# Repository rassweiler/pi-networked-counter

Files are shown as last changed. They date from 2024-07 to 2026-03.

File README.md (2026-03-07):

# pi-networked-counter
Network attached counter using Pi5, python, pyqt6, and sqlite

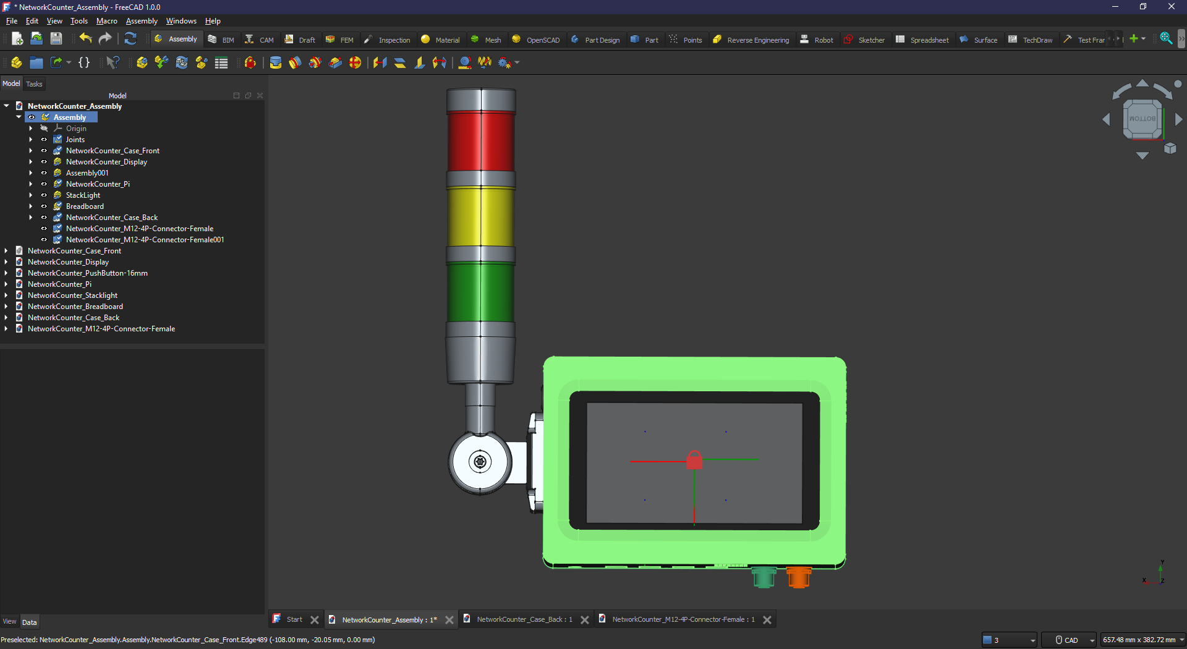
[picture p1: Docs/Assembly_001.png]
Assembly

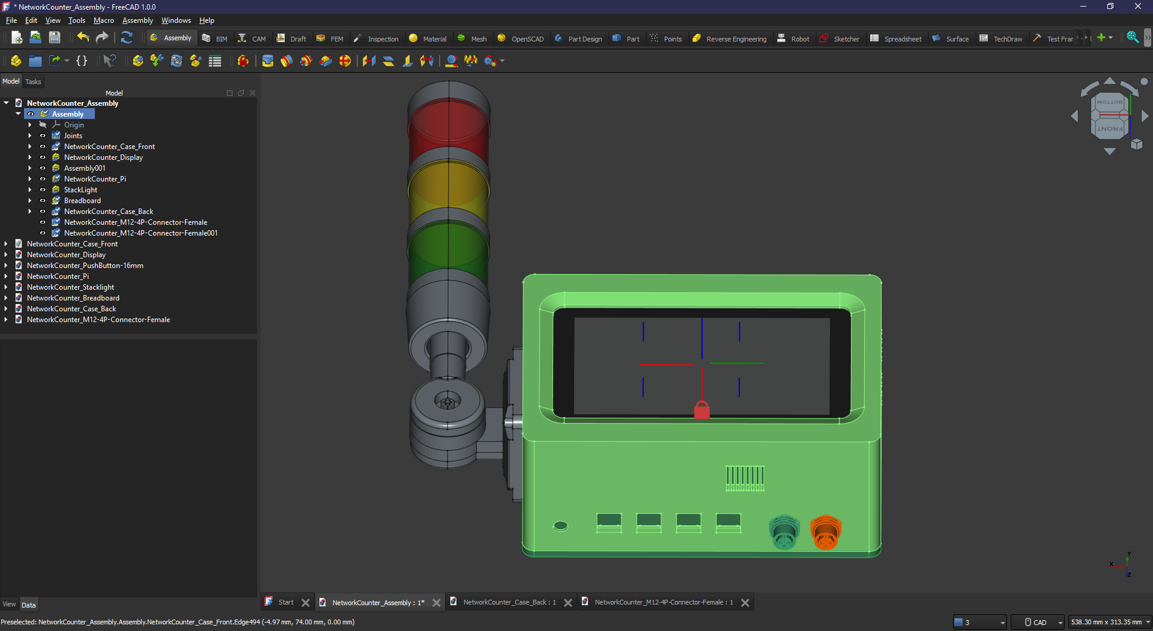
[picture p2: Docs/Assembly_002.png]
Assembly IO

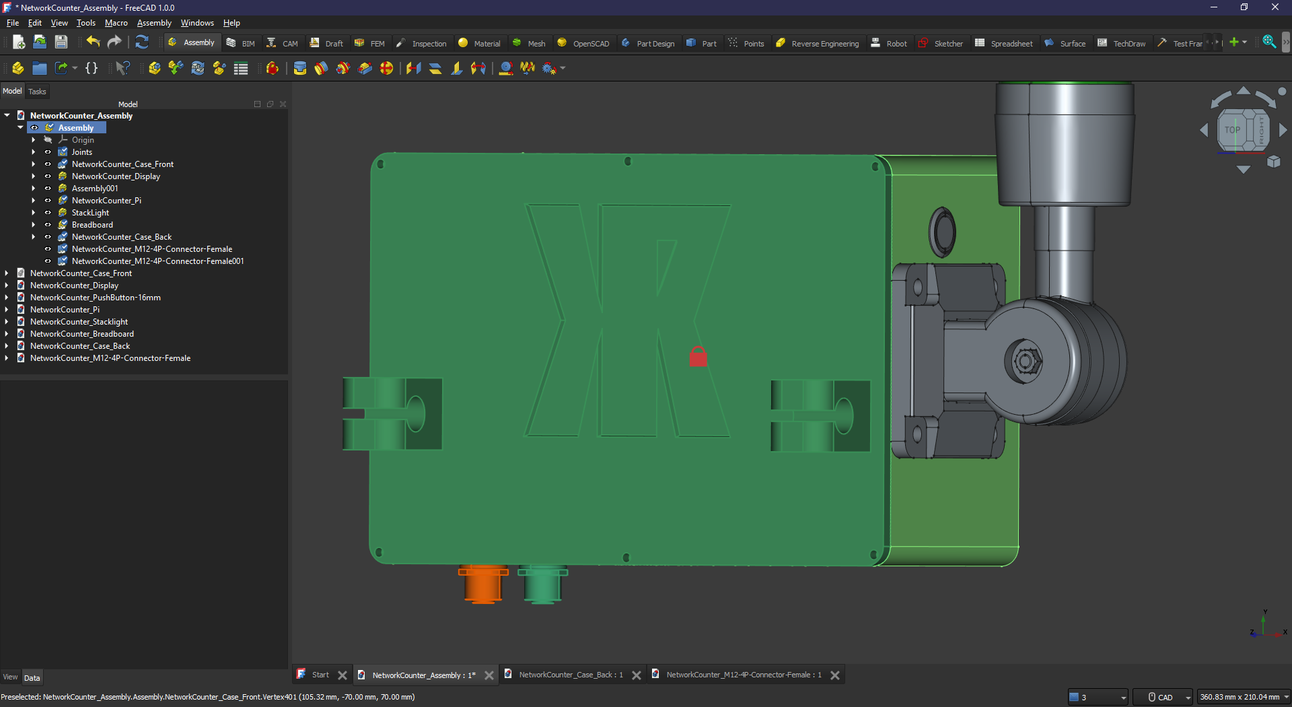
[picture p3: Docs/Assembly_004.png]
Assembly Rear

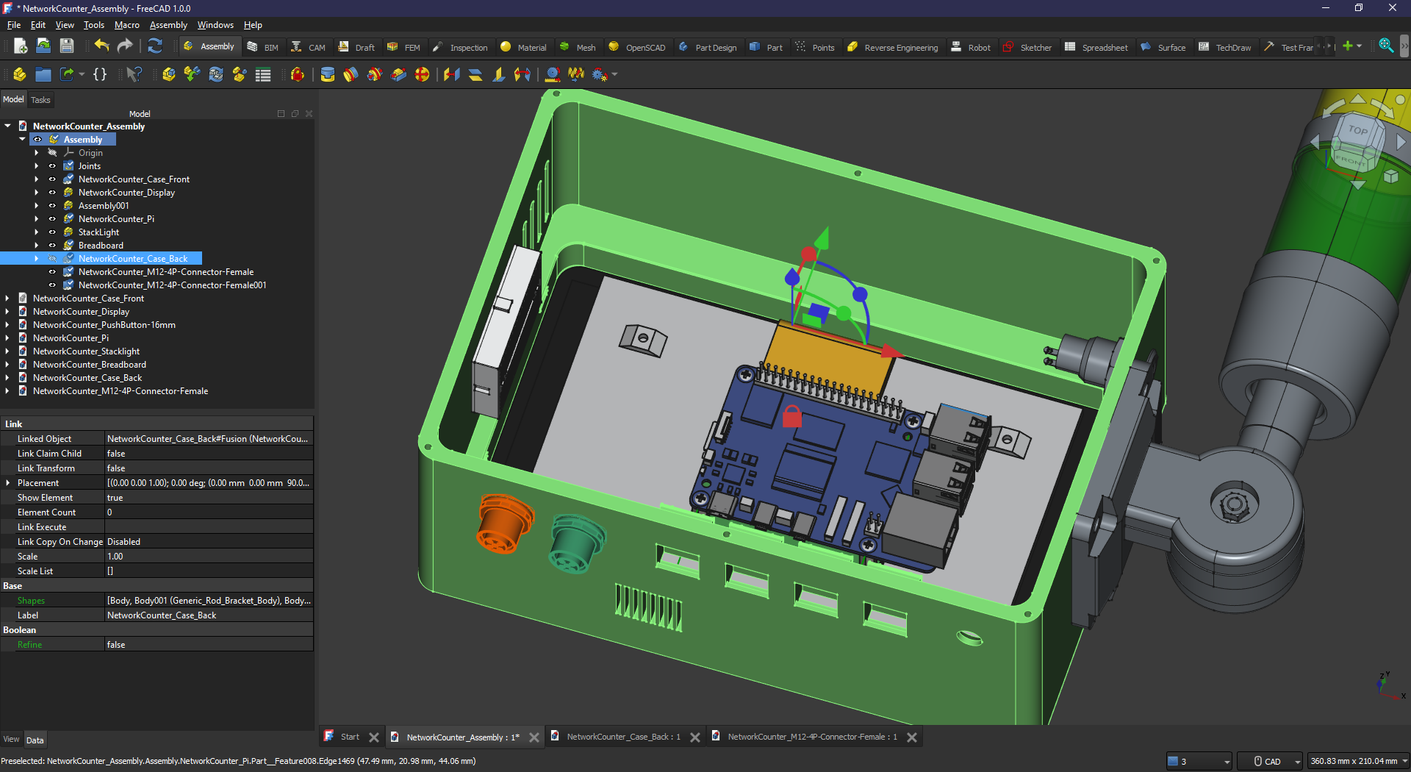
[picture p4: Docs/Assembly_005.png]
Assembly Opened

Sensor Assembly
Sensor Assembly 2
Sensor Assembly Opened

## Dev Setup (Linux)

- clone repository:
```
git clone https://github.com/rassweiler/pi-networked-counter.git && cd pi-networked-counter
```

- Setup python environment:
```
python3 -m venv venv

source venv/bin/activate

pip3 install gpiozero lgpio msal msal_extensions python-dotenv pygobject
```

- Install optional packages:
```
sudo apt install qtcreator sqlitebrowser
```

## Device Setup (Pi5+)

### Base Version Part List
- 1 [Raspberry Pi 5+](https://www.canakit.com/raspberry-pi-5-8gb.html?cid=CAD&src=raspberrypi)
- 1 [Raspberry Pi 5+ Power Supply](https://www.canakit.com/official-raspberry-pi-5-power-supply-27w-usb-c.html?defpid=4863)
- 1 [Micro SSD](https://www.amazon.ca/Samsung-Memory-Adapter-Limited-Warranty/dp/B09FFD6R2B/)
- 1 [Raspberry Pi 7" screen](https://www.canakit.com/raspberry-pi-lcd-display-touchscreen.html)
- 1 [Pi5 Diplay adapter cable](https://www.canakit.com/raspberry-pi-5-display-cable.html)
- 2 [Harting Cables](https://www.digikey.ca/en/products/detail/harting/21350102507010/16669171)
- 2 [M12 AMP Connector Male](https://www.digikey.ca/en/products/detail/te-connectivity-amp-connectors/T4171010005-001/7927449)
- 2 [M12 AMP Connector Female](https://www.digikey.ca/en/products/detail/te-connectivity-amp-connectors/T4171110005-001/7221411)
- 1 [Pack of jumper pin connectors](https://www.amazon.ca/Elegoo-120pcs-Multicolored-Breadboard-arduino/dp/B01EV70C78/)
- 1 [Roll of PETG filament](https://www.prusa3d.com/product/prusament-petg-anthracite-grey-1kg/)
- 2 [IR Emitter/ Receiver 5mm 3.3v](https://www.adafruit.com/product/2168#technical-details)
- 1 [Ethernet Keystone Inline](https://www.amazon.ca/5PACK-CAT6-Keystone-Inline-Coupler-White/dp/B0116T7XMQ/)
- 1 [Ethernet Patch Cable](https://www.amazon.ca/Cat-Ethernet-Cable-0-5ft-Pack/dp/B0CMQG7GS1)
- 1 [USB C Keystone Jack Adapter USB 3.1](https://www.amazon.ca/AAOTOKK-Keystone-Adapter-Type-C-Coupler/dp/B07Z947FRN)
- 1 [USB C patch cable](https://www.amazon.ca/Silkland-Charging-Compatible-MacBook-Samsung/dp/B0CQ4SX256)
- 1 [USB A Keystone Jack Cable](https://www.amazon.ca/Keystone-Haokiang-Adapters-Connector-Cable-20CM/dp/B07JFRLLQF)
- 1 [22awg Wire 2 Conductor 25ft](https://www.digikey.ca/en/products/detail/prysmian/C6348A-46-10/2761061)
- 1 [Rugged Metal Pushbutton - 16mm White Momentary](https://www.adafruit.com/product/558)
- 2 [Wire Connector Pack](https://www.amazon.ca/Connector-Solderless-Connectors-Stripping-Electrical/dp/B08929GXGK)
- 1 [GPIO Ribbon Cable](https://www.adafruit.com/product/1988)
- 1 [GPIO Header](https://www.pishop.ca/product/40-pin-gpio-connector-header/)

### Stacklight Version Part List
- 1 [DC Power Panel Jack](https://www.amazon.ca/DIYhz-Socket-Female-Mounting-Connector/dp/B079D6P26P)
- 1 [DC Power Supply](https://www.amazon.ca/ALITOVE-Adapter-Converter-100-240V-5-5x2-1mm/dp/B01GEA8PQA)
- 1 [Through-Hole Resistors - 1K ohm 5% 1/4W](https://www.adafruit.com/product/4294)
- 1 [Through-Hole Resistors - 220 ohm 5% 1/4W](https://www.adafruit.com/product/2780)
- 1 [AQY210EH SSR](https://www.digikey.ca/en/products/detail/panasonic-electric-works/AQY210EH/513082)
- 1 [Tower Light - Red Yellow Green Alert Light](https://www.adafruit.com/product/2993#technical-details)
- 1 [Tiny Premium Breadboard](https://www.adafruit.com/product/65#description)

### Optional Parts
- 1 [Pi5 POE Hat](https://www.pishop.ca/product/power-over-ethernet-hat-f-for-raspberry-pi-5-cooling-fan-802-3af-at/)

### Pi Software

- Update system
```
sudo apt update && sudo apt upgrade
```

- Install packages
```
sudo apt install < .packages
```

- Disable sudo NOPASSWD:
```
sudo nano /etc/sudoers.d/010_pi-nopasswd

remove NOPASSWD:
```

- Enable sudo logging:
```
sudo visudo

Insert:

Defaults    logfile=/var/log/sudo
```

- Harden ssh config:
```
sudo nano /etc/ssh/sshd_config

PermitRootLogin prohibit-password
MaxAuthTries 5
MaxSessions 3
MaxStartups 3:90:15
PasswordAuthentication no
```

- Harden ssh keys:
```
echo -e "# Restrict key exchange, cipher, and MAC algorithms, as per sshaudit.com\n# hardening guide.\n KexAlgorithms sntrup761x25519-sha512,sntrup761x25519-sha512@openssh.com,curve25519-sha256,curve25519-sha256@libssh.org,gss-curve25519-sha256-,diffie-hellman-group16-sha512,gss-group16-sha512-,diffie-hellman-group18-sha512,diffie-hellman-group-exchange-sha256\n\nCiphers chacha20-poly1305@openssh.com,aes256-gcm@openssh.com,aes256-ctr,aes192-ctr,aes128-gcm@openssh.com,aes128-ctr\n\nMACs hmac-sha2-256-etm@openssh.com,hmac-sha2-512-etm@openssh.com,umac-128-etm@openssh.com\n\nHostKeyAlgorithms sk-ssh-ed25519-cert-v01@openssh.com,ssh-ed25519-cert-v01@openssh.com,rsa-sha2-512-cert-v01@openssh.com,rsa-sha2-256-cert-v01@openssh.com,sk-ssh-ed25519@openssh.com,ssh-ed25519,rsa-sha2-512,rsa-sha2-256\n\nRequiredRSASize 3072\n\nCASignatureAlgorithms sk-ssh-ed25519@openssh.com,ssh-ed25519,rsa-sha2-512,rsa-sha2-256\n\nGSSAPIKexAlgorithms gss-curve25519-sha256-,gss-group16-sha512-\n\nHostbasedAcceptedAlgorithms sk-ssh-ed25519-cert-v01@openssh.com,ssh-ed25519-cert-v01@openssh.com,sk-ssh-ed25519@openssh.com,ssh-ed25519,rsa-sha2-512-cert-v01@openssh.com,rsa-sha2-512,rsa-sha2-256-cert-v01@openssh.com,rsa-sha2-256\n\nPubkeyAcceptedAlgorithms sk-ssh-ed25519-cert-v01@openssh.com,ssh-ed25519-cert-v01@openssh.com,sk-ssh-ed25519@openssh.com,ssh-ed25519,rsa-sha2-512-cert-v01@openssh.com,rsa-sha2-512,rsa-sha2-256-cert-v01@openssh.com,rsa-sha2-256\n\n" > /etc/ssh/sshd_config.d/ssh-audit_hardening.conf
```

- Remove avahi:
```
sudo systemctl stop avahi-daemon && sudo systemctl disable avahi-daemon

sudo apt purge avahi-daemon -y
```

- Remove CUPS:
```
sudo systemctl stop cups && sudo systemctl disable cups

sudo apt purge cups -y 
```

- PI configure
Set the locale to UTF-8

- Setup keyring for sharepoint integration
Run seahorse and make sure there is a default keystore

- clone repository to PI:
```
git clone https://github.com/rassweiler/pi-networked-counter.git && cd pi-networked-counter
```

- Copy the desktop file to autostart the app:
```
sudo cp objectcounter.desktop /etc/xdg/autostart/objectcounter.desktop
```

- Add panel icon
```
cp objectcounter.desktop ~/.local/share/applications/
```

Then restart the system to get the app in the menu under other, then right click the app and select add to taskbar

- Setup startup IO for push button
```
echo "dtoverlay=gpio-poweroff,gpiopin=25,active_low" >> /boot/firmware/config.txt
```

### Sharepoint Setup (Optional)

- Add to the `.settup.toml` file your sharepoint access details:
```
[sharepoint]
authority = "https://login.microsoftonline.com/{AID}"
client = "{CID}"
scopes = 'User.ReadBasic.All Files.ReadWrite Sites.ReadWrite.All'
endpoint = "https://graph.microsoft.com/v1.0/me" 
```

- run the `get_token.sh` script once to initialise your sharepoint token, it should provide a link and a key to login using a browser.

### Print Parts

- Print out the [Front case](./Models/Exports/NetworkCounter_Case_Front_Print.3mf) section (Should contain the screen brackets as well)
- Print out the [Rear case](./Models/Exports/NetworkCounter_Case_Back_Print.3mf) section
- Print out the [Sensor case](./Models/Exports/NetworkCounter_SensorCase_Front_Print.3mf) sections
- Print any required brackets/stands

### Prepare Sensors

- Connect both power wires together from the IR emitter and receiver
- Connect both ground wires together from the IR emitter and receiver
- Solder the M12 AMP Connector Male to the sensors following the pinout below

### Sensor Pinout To Cable

- Pin 1 (Brown): 3.3V 
- Pin 2 (White): Unused 
- Pin 3 (Blue): Emitter signal (Yellow) 
- Pin 4 (Black): Ground 
- Pin 5 (Gray): Unused
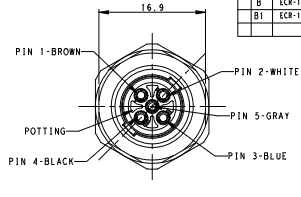
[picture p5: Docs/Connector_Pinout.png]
Connector Pinout


### Lightstack Pinout

- Cable Brown: 12V 
- Cable Green: Green LED 
- Cable Yellow: Yellow LED 
- Cable Red: Red LED 

### Pi5 Wiring 

- Pin 1 (3.3V): To infeed sensor pin 1
- Pin 2 (5V): To Display pin 5 (5V)
- Pin 6 (GND): To Display pin 1 (GND)
- Pin 9 (GND): To infeed sensor pin 4
- Pin 11: To infeed sensor pin 3
- Pin 13: To stack light green wire
- Pin 14 (GND): To outfeed sensor pin 4
- Pin 15: To stack light yellow wire
- Pin 16: To outfeed sensor pin 3
- Pin 17: (3.3V): To outfeed sensor pin 1
- Pin 18: To stack light red wire
- Pin 22: To power led +
- Pin 25 (GND): To dev board for ground
- Pin 30 (GND): To power led -

### Assembly Schematic
The Pi5 board is not entirely accurate, the J2 and J8 pins are proper however.
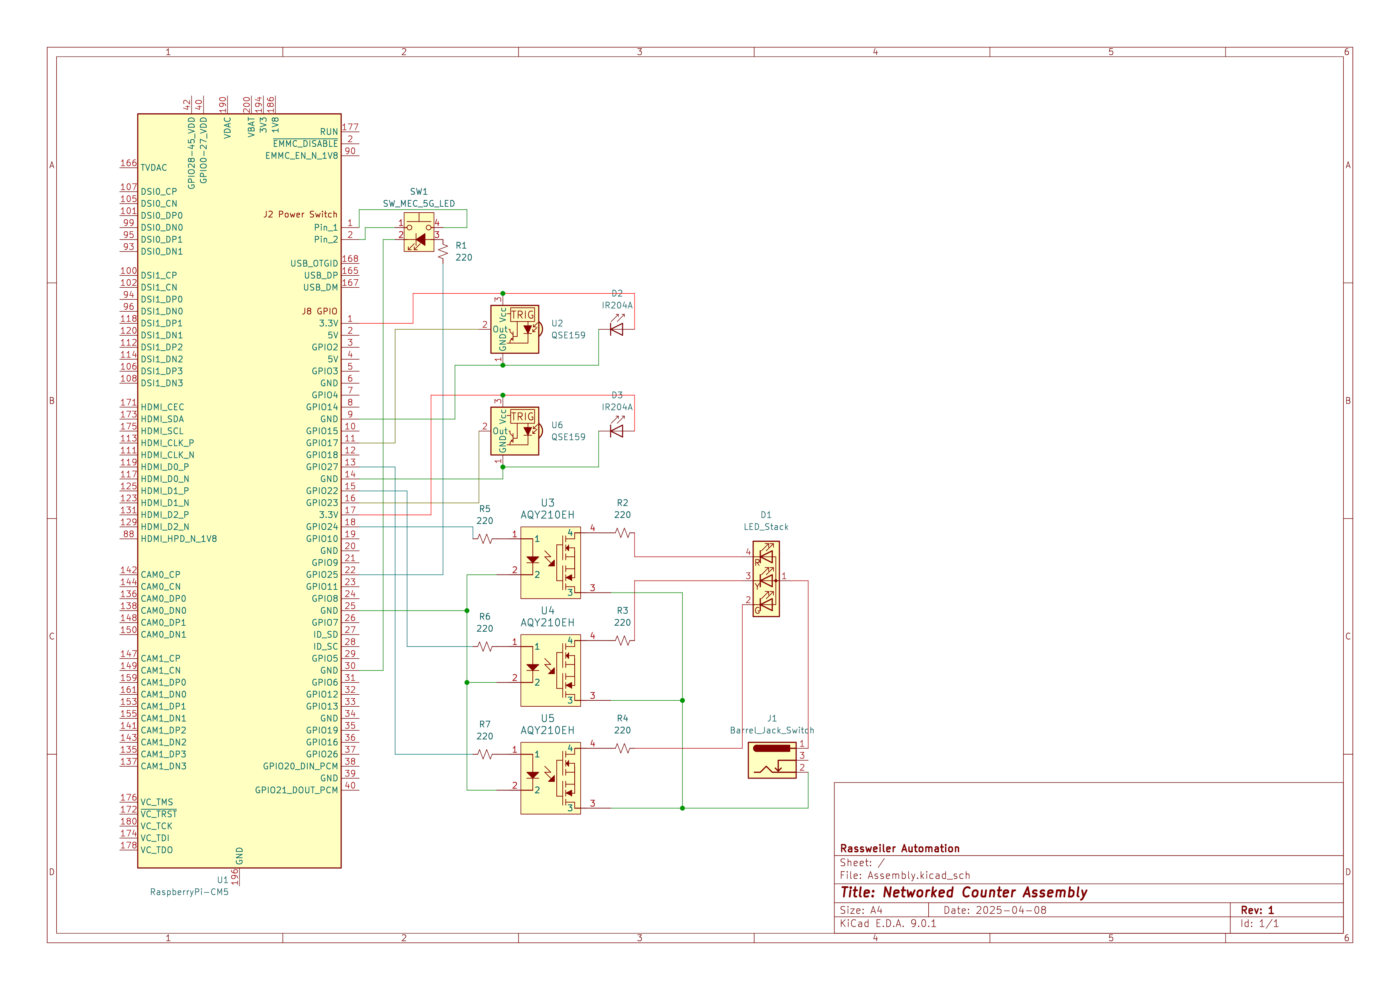
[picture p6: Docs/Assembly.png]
Schematic


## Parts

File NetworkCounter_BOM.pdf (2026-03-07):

Name | Part # | Unit Price

### Units Per Counter

Total Cost | Link | Purchased | Tracking Number
Harting Cable | 21348485484050 | $27.26
2 | $54.52 | https://www.digikey.ca/en/products/detail/harting/21348485484050/7917624
| | Y | Delivered
M12 AMP Connector Male | T4171010005-001 | $15.14
2 | $30.28 | https://www.digikey.ca/en/products/detail/te-connectivity-amp-connectors/T4171010005-001/7927449
| | Y | Delivered
M12 AMP Connector Female | T4171310004-001 | $14.20
2 | $28.40 | https://www.digikey.ca/en/products/detail/te-connectivity-amp-connectors/T4171310004-001/7221375
| | Y | Delivered
Tall Headers 4 & 40 | $11.95
1 | $11.95 | https://www.pishop.ca/product/4-40-pin-extra-tall-header-push-fit-version-poe-hat-set/
| | Y | Delivered
Pi5 POE Hat | $33.95
1 | $33.95 | https://www.pishop.ca/product/power-over-ethernet-hat-f-for-raspberry-pi-5-cooling-fan-802-3af-at/
| | Y | Delivered
Raspberry Pi 5 8GB | $111.95
1 | $111.95 | https://www.canakit.com/raspberry-pi-5-8gb.html?cid=CAD&src=raspberrypi
| | Y | Delivered
Jumper Pin Connectors | $12.99
1 | $12.99 | https://www.amazon.ca/Elegoo-120pcs-Multicolored-Breadboard-arduino/dp/B01EV70C78/
| | Y | Delivered
Breadboard | 340-002-1 | $75.54
1 | $75.54 | https://www.digikey.ca/en/products/detail/digilent-inc/340-002-1/9556131
| | Y | Delivered
Raspberry Pi 7" Touchscreen | RSP-DISPLAY | $85.95
1 | $85.95 | https://www.canakit.com/raspberry-pi-lcd-display-touchscreen.html
| | Y | Delivered
Raspberry Pi 5 Display Cable | CBL-DISP-MINI-200 | $1.40
1 | $1.40 | https://www.canakit.com/raspberry-pi-5-display-cable.html
| | Y | Delivered
Raspberry Pi 5 Power Supply | $16.95
1 | $16.95 | https://www.canakit.com/official-raspberry-pi-5-power-supply-27w-usb-c.html?defpid=4863
| | Y | Delivered
Fillamentum Ghost White PETG Filament - 1.75mm | M-US3-YXAA | $56.00
1 | $56.00 | https://www.matterhackers.com/store/l/fillamentum-petg-filament/sk/MUS3YXAA
| | Y | Delivered
Micro HDMI to HDMI Adapter | $12.99
1 | $12.99 | https://www.amazon.ca/Cable-Matters-Plated-Female-Adapter/dp/B00JDRHQ58/
| | Y | Delivered
Samsung 256GB EVO Plus Micro SD | MB-MC256K | $32.49
1 | $32.49 | https://www.amazon.ca/Samsung-Memory-Adapter-Limited-Warranty/dp/B09FFD6R2B/
| | Y | Delivered
Memory Card Reader | $13.99
1 | $13.99 | https://www.amazon.ca/Memory-Reader-BENFEI-USB-C-Adapter/dp/B08P517NW5/
| | Y | Delivered
Ultrasonic Distance Sensor - 3.3V | US-100 | $5.95
2 | $11.90 | https://www.pishop.ca/product/us-100-ultrasonic-sensor-with-temperature-compensation-range/
| | Y | Delivered
Ethernet Wall Plate 1 Port Cat6 RJ45 Keystone | $9.99
1 | $9.99 | https://www.amazon.ca/VCE-Ethernet-Keystone-Coupler-Network/dp/B0C3J1FZZN/
| | Y | Delivered
Cat6 1' Patch Cables | $13.99
1 | $13.99 | https://www.amazon.ca/Cable-Matters-5-Pack-Snagless-Ethernet/dp/B00C4U030G
| | Y | Delivered
USB C Keystone Jack Cable | $10.19
1 | $10.19 | https://www.amazon.ca/Poyiccot-Keystone-Cable-White-Black/dp/B08BJJZV2Z
USB A Keystone Jack Cable | $11.51
1 | $11.51 | https://www.amazon.ca/Keystone-Haokiang-Adapters-Connector-Cable-20CM/dp/B07JFRLLQF

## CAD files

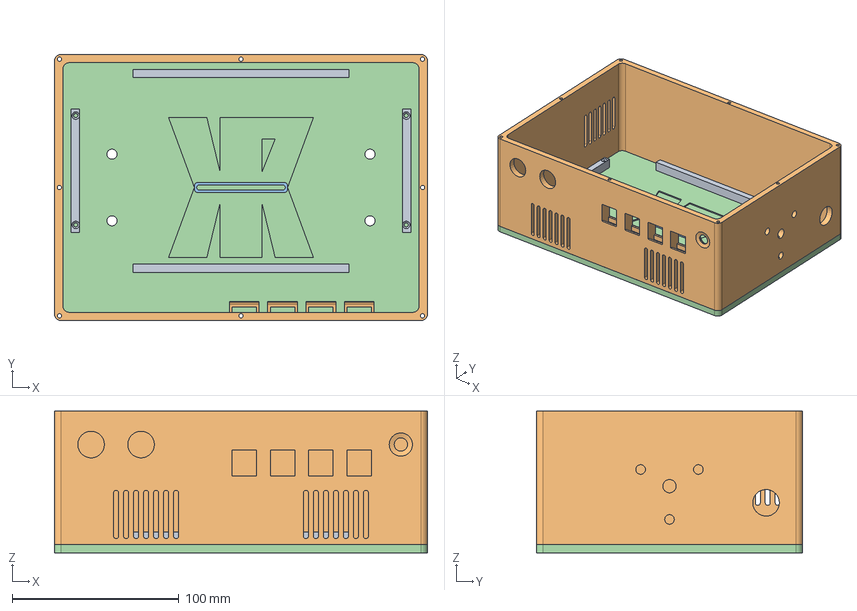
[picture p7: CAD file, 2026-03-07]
Models/NetworkCounter_Case.FCStd
224.0 x 160.0 x 85.0 mm
NetworkCounter_Case_Face
NetworkCounter_Case_Walls
NetworkCounter_Case_Bracket
NetworkCounter_Case_Cover

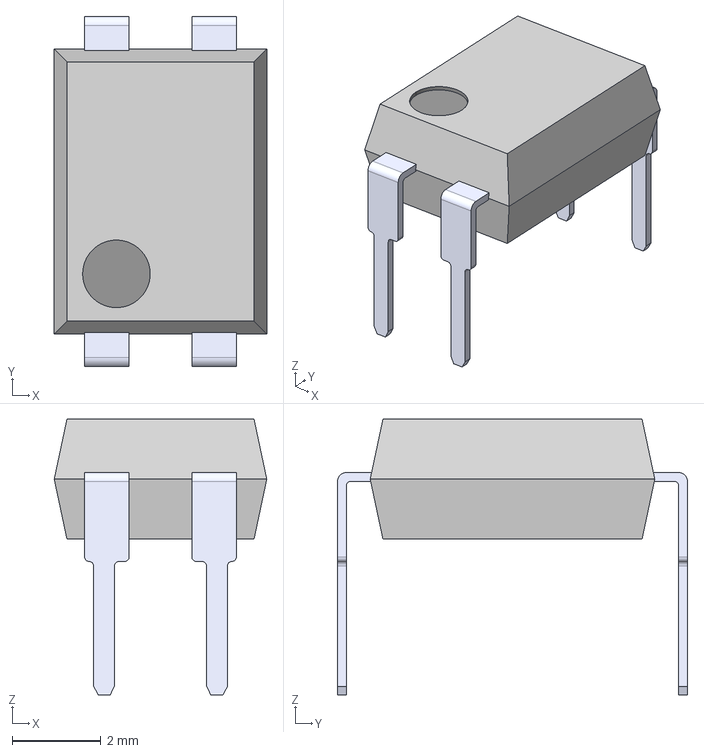
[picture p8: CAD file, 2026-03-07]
Schematics/LED_Board/panasonic_AQY210EH.step
4.78 x 7.87 x 6.20 mm

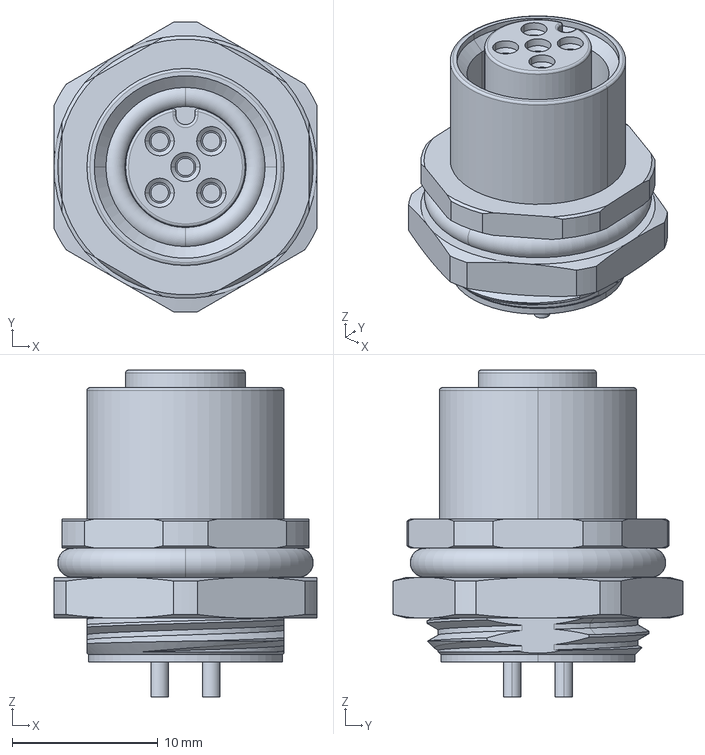
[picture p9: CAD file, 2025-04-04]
Models/NetworkCounter_M12-4P-Connector-Female.FCStd
18.0 x 19.9 x 22.4 mm

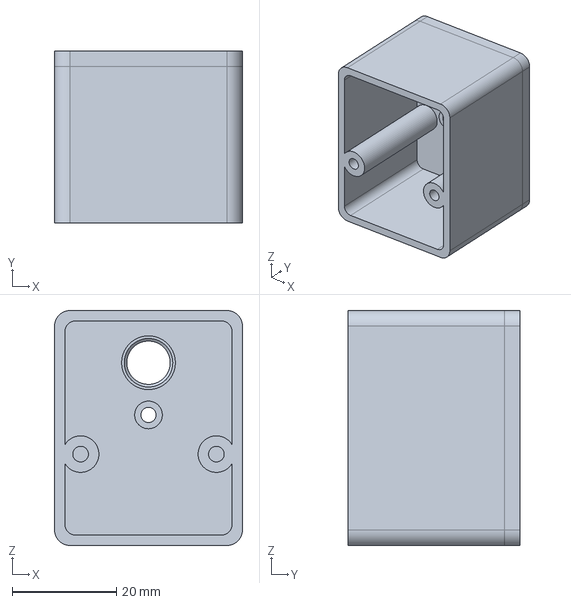
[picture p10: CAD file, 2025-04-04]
Models/NetworkCounter_SensorCase_Front_Emitter.FCStd
36.0 x 33.0 x 45.0 mm

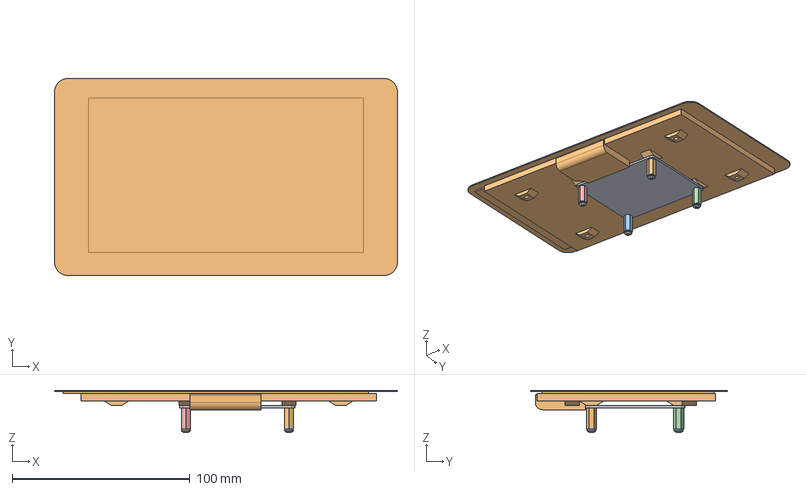
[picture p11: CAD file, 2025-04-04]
Models/NetworkCounter_Display.FCStd
193.0 x 110.8 x 23.9 mm
RPi Display Driver PCB v1
Standoff M2.5 12mm v2
Standoff M2.5 12mm v003
Standoff M2.5 12mm v004
Standoff M2.5 12mm v005
M2.5 Screw
M2.5 Screw001
M2.5 Screw002
M2.5 Screw003
RPi Touchscreen Module

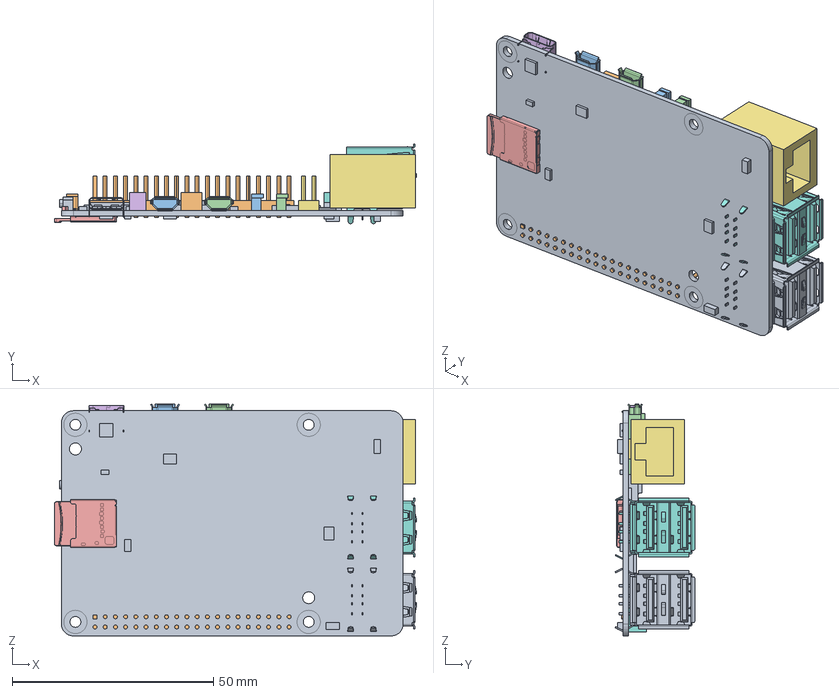
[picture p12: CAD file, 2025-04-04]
Models/NetworkCounter_Pi.FCStd
90.0 x 19.8 x 57.7 mm
PCB_for REF 060923
GPIO Header for REF
Micro HDMI for REF
Micro HDMI for REF001
SD CARD for REF
USB-C for REF
RJ45 for REF
USB for REF
USB for REF001
PCIe for REF
CAM-DISP for REF
CAM-DISP for REF001
LED for REF
BAT Header for REF
PoE Header for REF
FAN Header for REF
SWITCH for REF
UART for REF

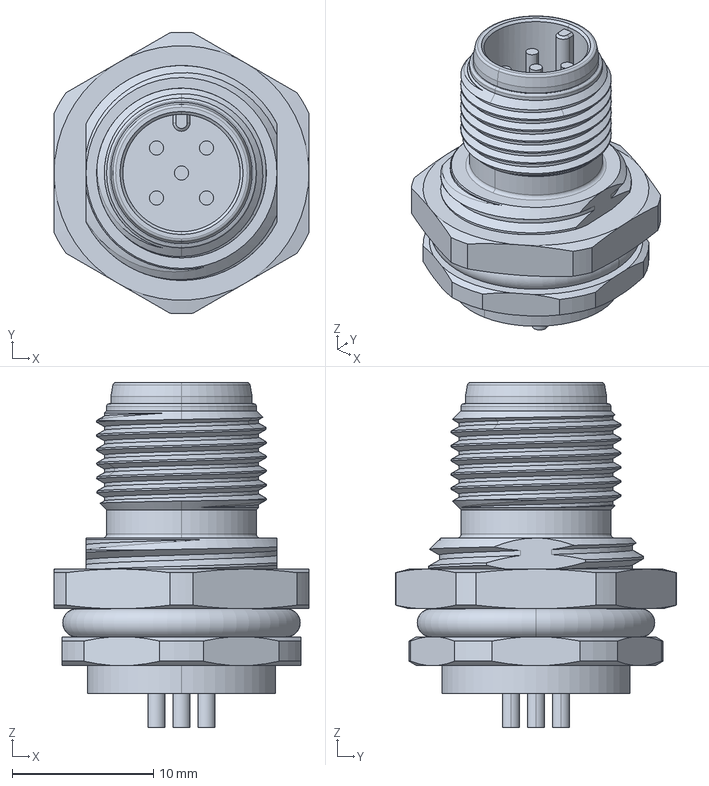
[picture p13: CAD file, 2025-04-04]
Models/NetworkCounter_M12-5P-Connector-Male.FCStd
18.0 x 19.9 x 24.4 mm

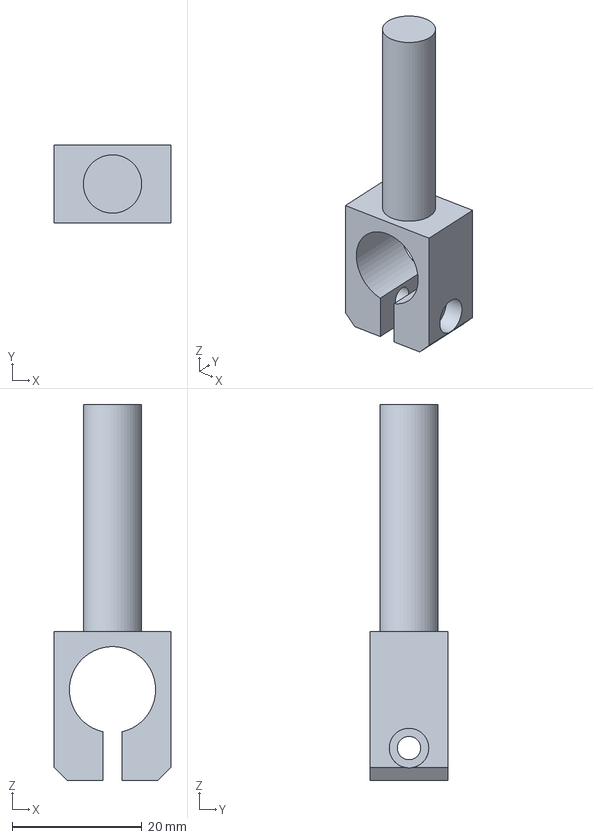
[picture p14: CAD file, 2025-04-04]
Models/NetworkCounter_Adapter_13mmHorizontal_9mmVertical.FCStd
18.0 x 12.0 x 58.0 mm

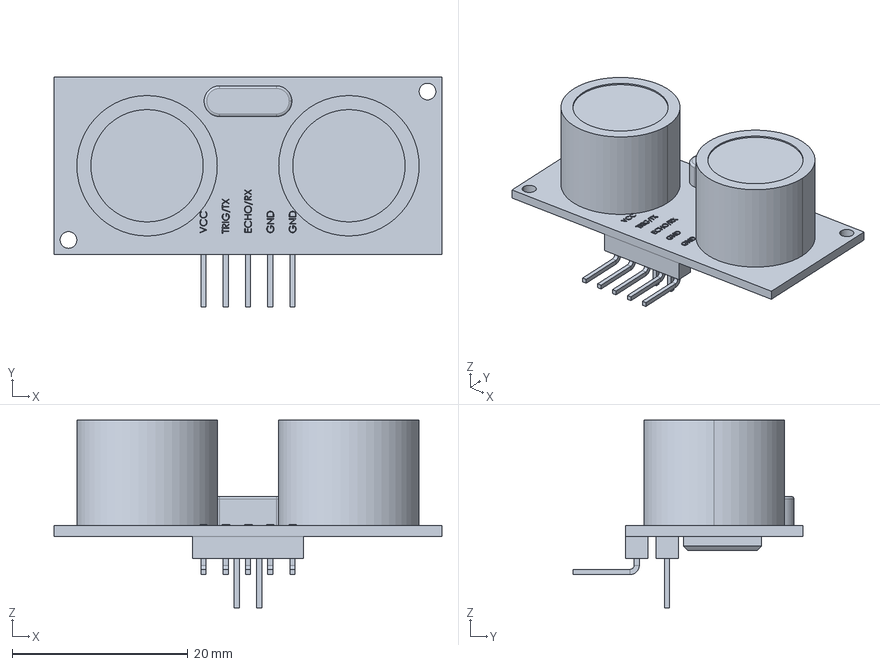
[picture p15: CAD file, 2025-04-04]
Models/NetworkCounter_US-100.FCStd
44.2 x 26.2 x 21.4 mm

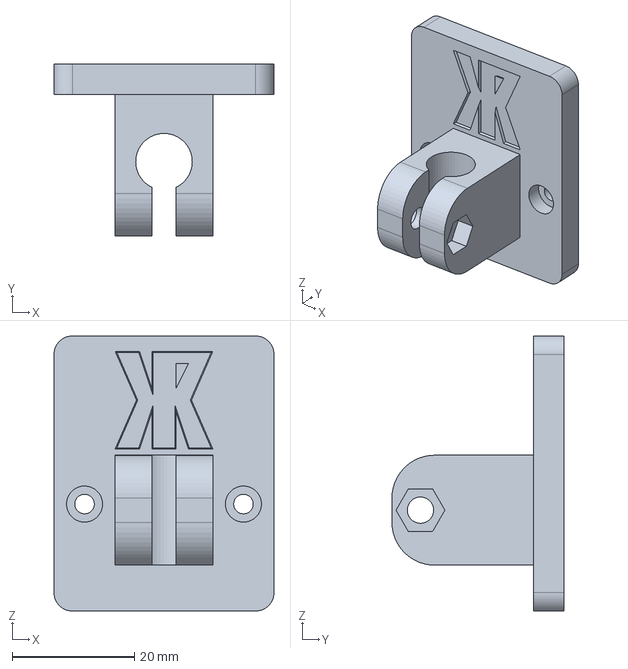
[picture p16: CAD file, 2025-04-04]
Models/NetworkCounter_SensorCase_Back.FCStd
36.0 x 28.2 x 45.0 mm

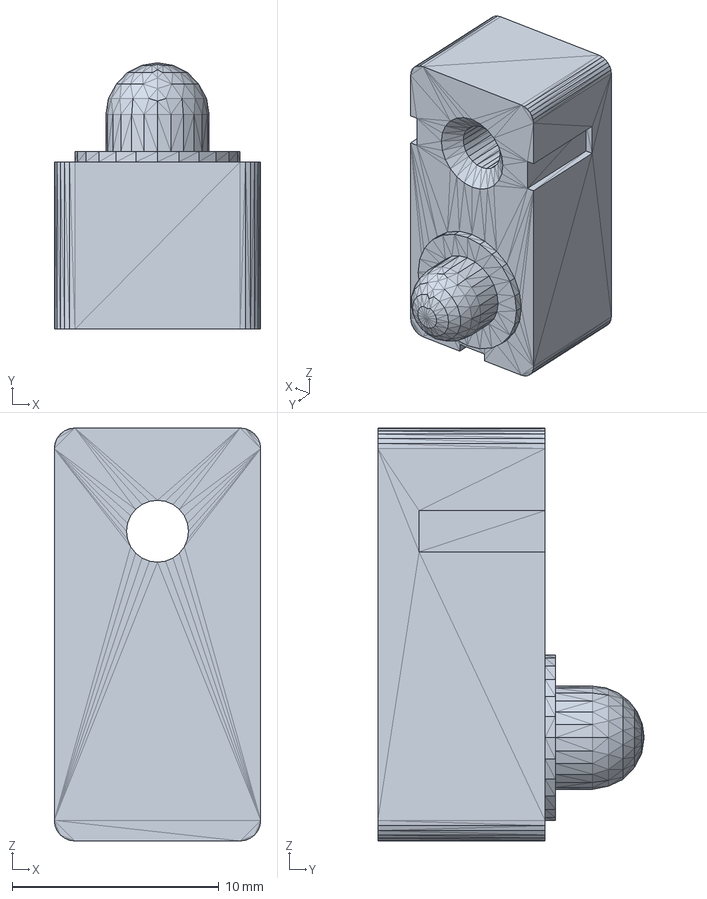
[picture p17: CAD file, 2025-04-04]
Models/NetworkCounter_IR_5mm.FCStd
10.0 x 12.9 x 20.0 mm

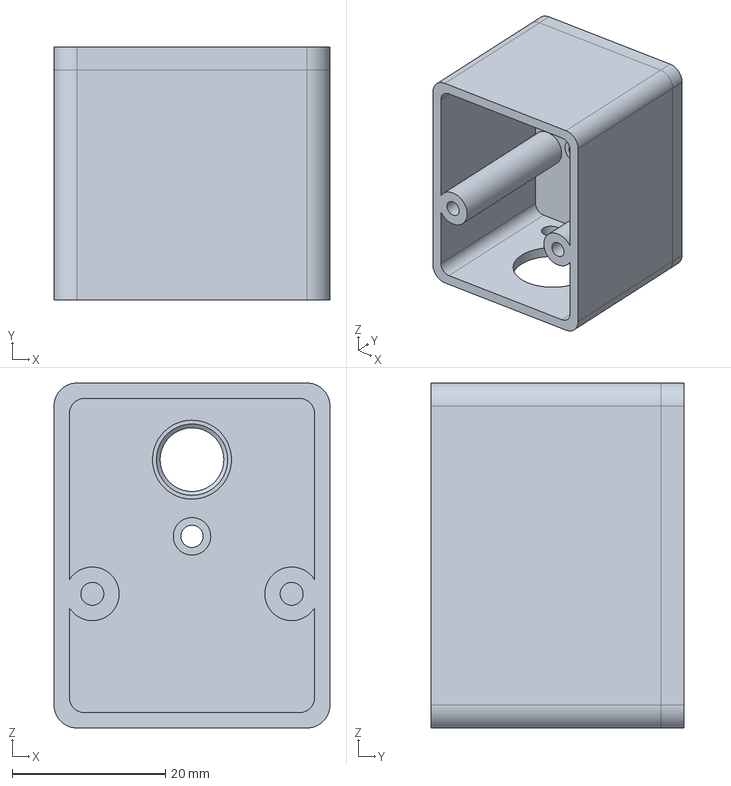
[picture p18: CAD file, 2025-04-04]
Models/NetworkCounter_SensorCase_Front_Receiver.FCStd
36.0 x 33.0 x 45.0 mm

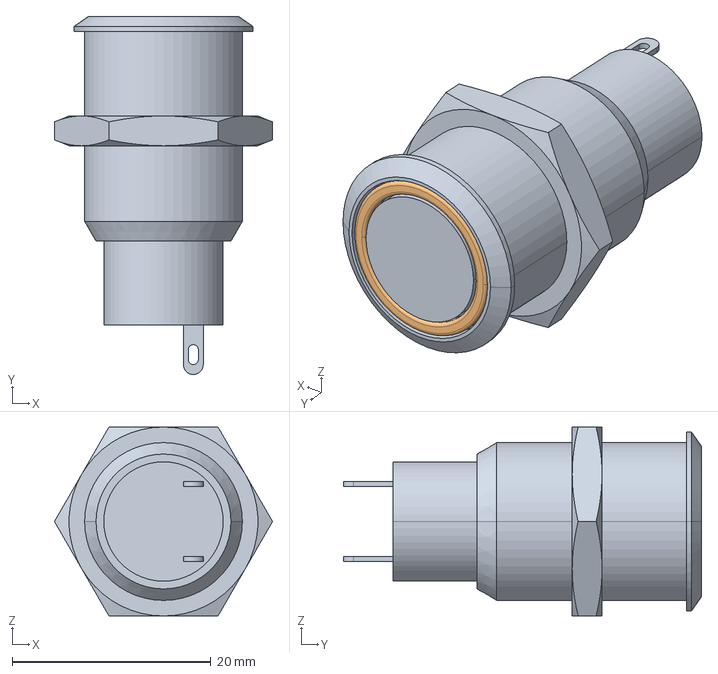
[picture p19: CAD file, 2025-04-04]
Models/NetworkCounter_PushButton-16mm.FCStd
21.9 x 36.0 x 19.0 mm
SWITCH_COM-119XX
SWITCH_COM-119XX001

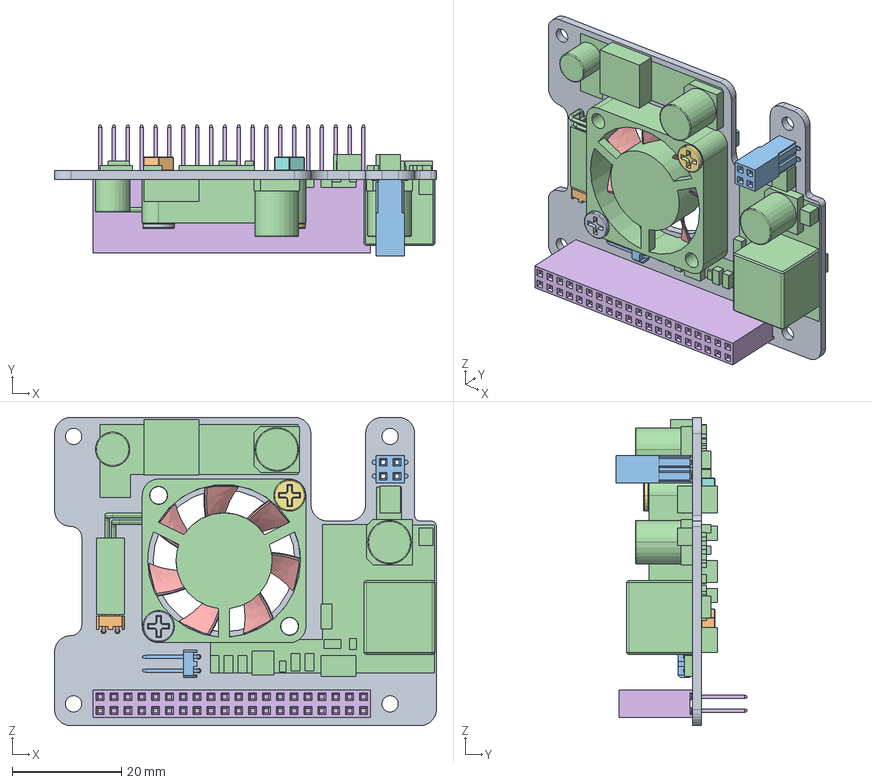
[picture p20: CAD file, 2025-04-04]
Models/NetworkCounter_POE.FCStd
70.0 x 24.1 x 56.5 mm
POE-HAT-F_PCBA
2_54_MM_DUPONT_MALE_2PIN-SMT
2_54_MM_DUPONT_MALE_2PIN-SMT001
2_54MM-H13_5-6-2X20PIN
CM2_5X12-5-SCREW
M2_5-NUT
CM2_5X12-5-SCREW001
M2_5-NUT001
HEADER-SMD-F-2_54X4P-H13_5
CORE-01

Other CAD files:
Models/NetworkCounter_Adapter_9mmHorizontal_9mmVertical.FCStd
Schematics/LED_Board/panasonic_AQY210EH.dxf

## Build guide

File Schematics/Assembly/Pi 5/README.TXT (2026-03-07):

These files have been created in version 8 of KiCAD.

Some of the 3d models need to be downloaded form the following places and put into the CM5IO.3shapes directory some models are approximations.

https://datasheets.raspberrypi.org/cm5/CM5-step.zip
https://www.molex.com/molex/products/part-detail/memory_card_socket/5033981892

The models provided in the 3dmodels directory are from various manufacturers including Diodes, Hirose, MTCONN, Toby, TRXCOM. Terms and conditions for the use of the models remain with the original manufacture.

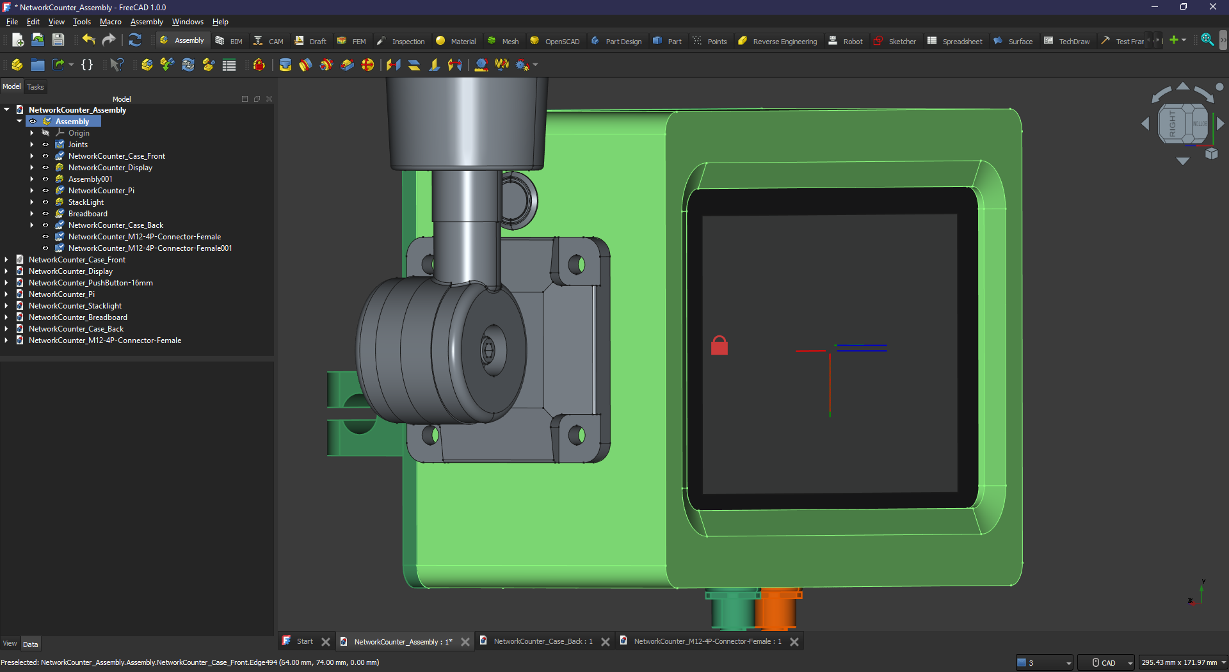
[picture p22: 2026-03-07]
Docs/Assembly_003.png

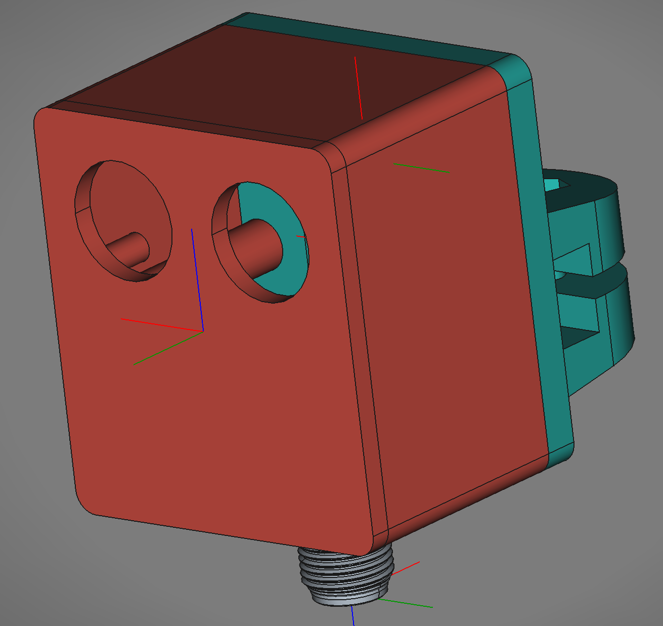
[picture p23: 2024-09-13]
Docs/SensorAssembly_01.png

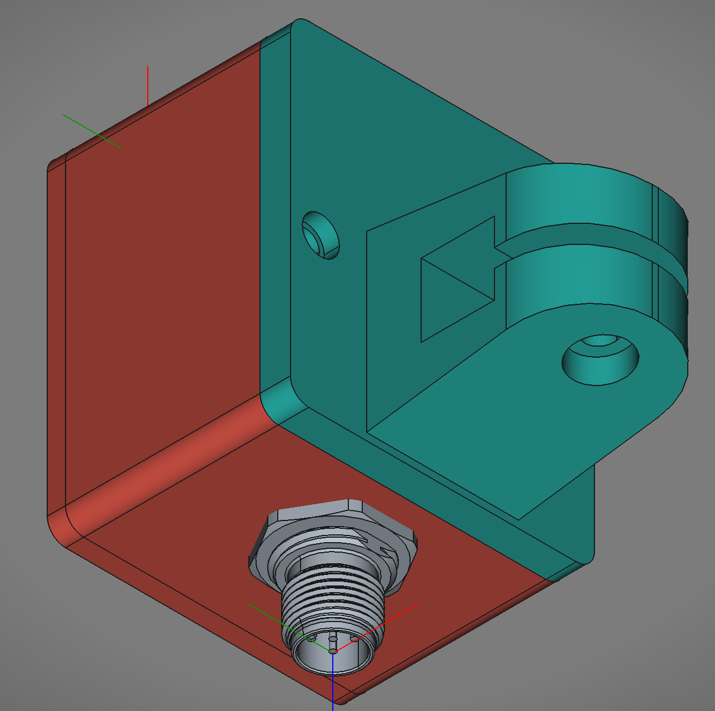
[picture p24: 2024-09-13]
Docs/SensorAssembly_02.png

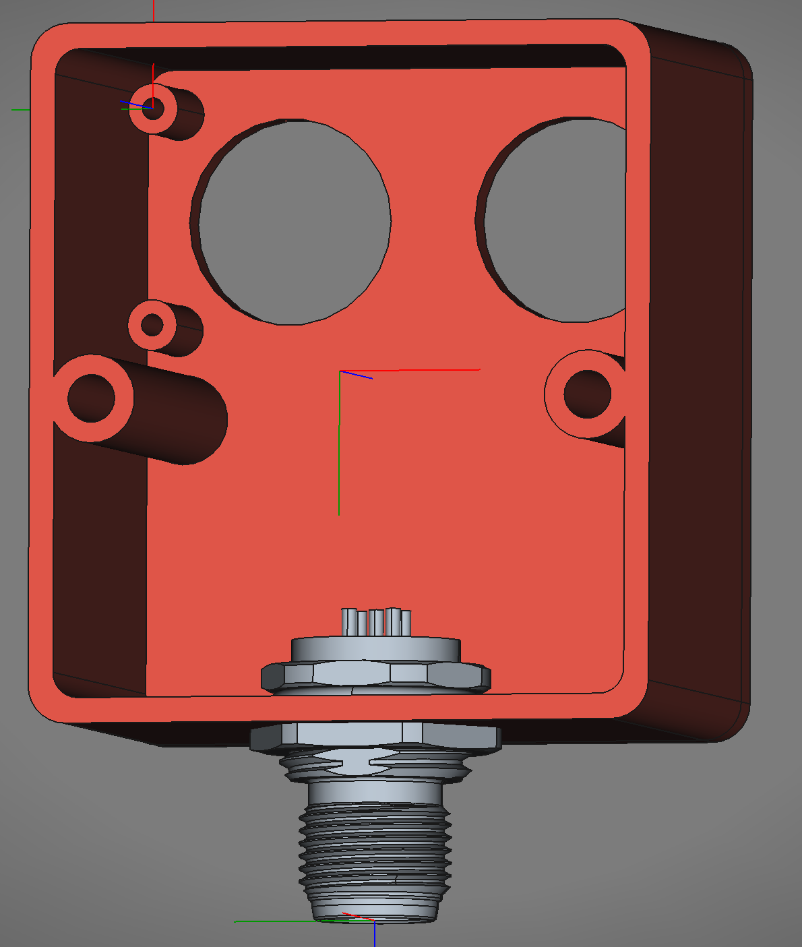
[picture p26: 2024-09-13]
Docs/SensorAssembly_03.png

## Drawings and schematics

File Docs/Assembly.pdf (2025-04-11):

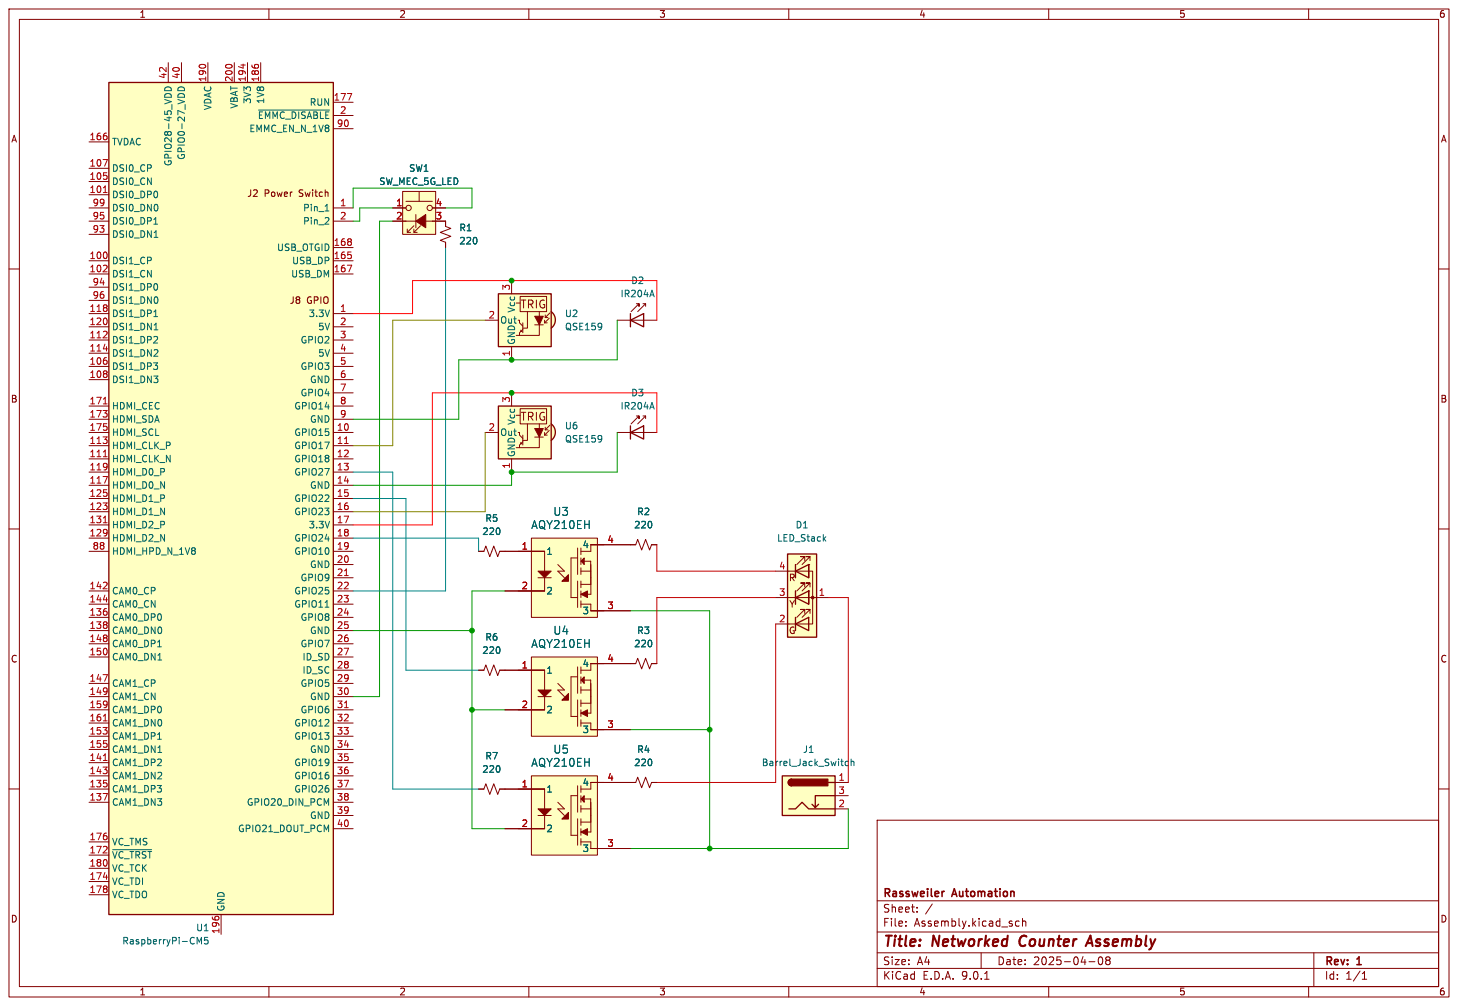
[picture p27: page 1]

File: Assembly.kicad_sch Sheet: / Rassweiler Automation

Id: 1/1 Title: Networked Counter Assembly

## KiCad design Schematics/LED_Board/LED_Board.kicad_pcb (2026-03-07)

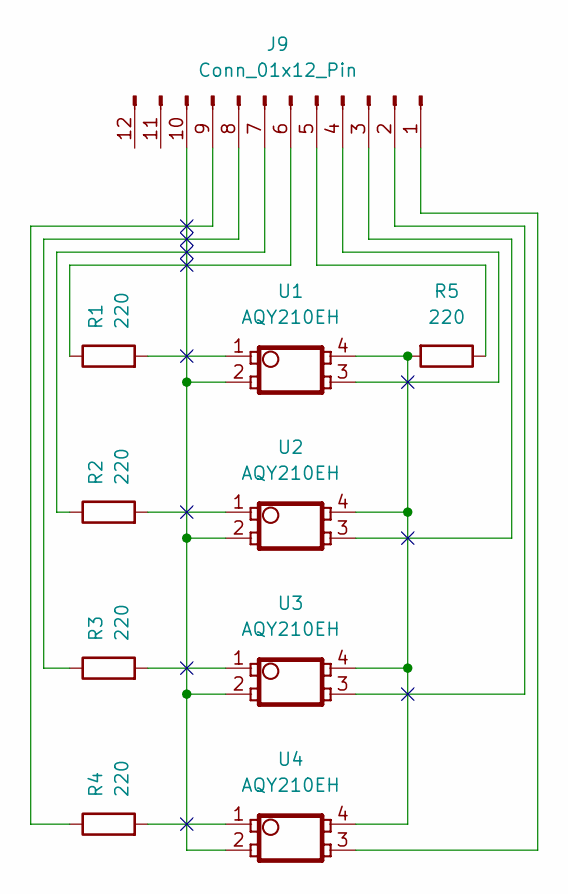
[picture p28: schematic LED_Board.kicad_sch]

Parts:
J9: Conn_01x12_Pin; PinHeader_1x12_P2.54mm_Vertical
R1, R2, R3, R4, R5: 220; R_Axial_DIN0204_L3.6mm_D1.6mm_P5.08mm_Horizontal
U1, U2, U3, U4: AQY210EH; Panasonic_AQY210EH

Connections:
unnamed: J9.1, U4.3
unnamed: J9.2, U3.3
unnamed: J9.3, U2.3
unnamed: J9.4, U1.3
unnamed: J9.5, R5.1
unnamed: J9.6, R1.1
unnamed: J9.7, R2.1
unnamed: J9.8, R3.1
unnamed: J9.9, R4.1
unnamed: J9.10, U1.2, U2.2, U3.2, U4.2
unnamed: R1.2, U1.1
unnamed: R2.2, U2.1
unnamed: R3.2, U3.1
unnamed: R4.2, U4.1
unnamed: R5.2, U1.4, U2.4, U3.4, U4.4

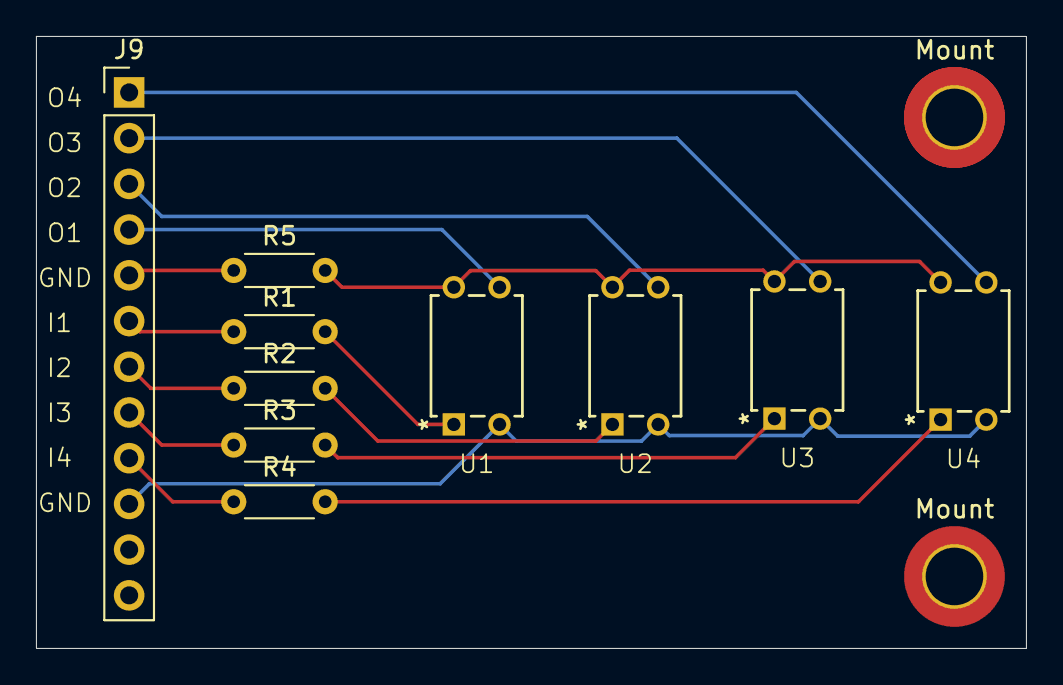
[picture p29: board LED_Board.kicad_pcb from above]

Board: 2 copper layers, 55.0 x 34.0 mm, 12 parts (0 on the bottom side), 15 nets.

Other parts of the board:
Mount: MountingHole_3.2mm_M3_DIN965_Pad_TopBottom
Mount#2: MountingHole_3.2mm_M3_DIN965_Pad_TopBottom

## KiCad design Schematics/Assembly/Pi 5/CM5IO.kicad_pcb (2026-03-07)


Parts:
C9, C18: 100n; C_0402_1005Metric; Part Description 0.1uF 10% 16V Ceramic Capacitor X7R 040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
H1, H2, H3, H4, H5, H6, H7, H8: MountingHole; MountingHole_2.7mm_M2.5_DIN965; Part Description M2.5 mounting hole; not fitted
J11: USB_C_Receptacle_USB2.0; USB_C_Receptacle_GCT_USB4105-xx-A_16P_TopMnt_Horizontal; Part Description USBC USB2 data and power connector
R9: 2.2K 1%; R_0402_1005Metric; Part Description Resistor 2.2K M1005 1% 63mW

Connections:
/+5v: C9.1, C18.1, J11.A4 (VBUS), J11.A9 (VBUS), J11.B4 (VBUS), J11.B9 (VBUS), R9.1; also elsewhere on the board
/CC1: J11.A5 (CC1); also elsewhere on the board
/CC2: J11.B5 (CC2); also elsewhere on the board
/USB2_N: J11.A7 (D-), J11.B7 (D-); also elsewhere on the board
/USB2_P: J11.A6 (D+), J11.B6 (D+); also elsewhere on the board
GND: C9.2, C18.2, J11.A1 (GND), J11.A12 (GND), J11.B1 (GND), J11.B12 (GND), J11.S1 (SHIELD), R9.2; also elsewhere on the board

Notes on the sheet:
Connectors ------- Ethernet SDCARD 40way RPI Jumpers Fan Battery
Connectors ------ M2 MKey
Discharge Resistor Needed by some Type C PSUs
TypeC Power connector
Connectors ------- HDMI 0 HDMI 1 CSI/DSI 0 CSI/DSI 1

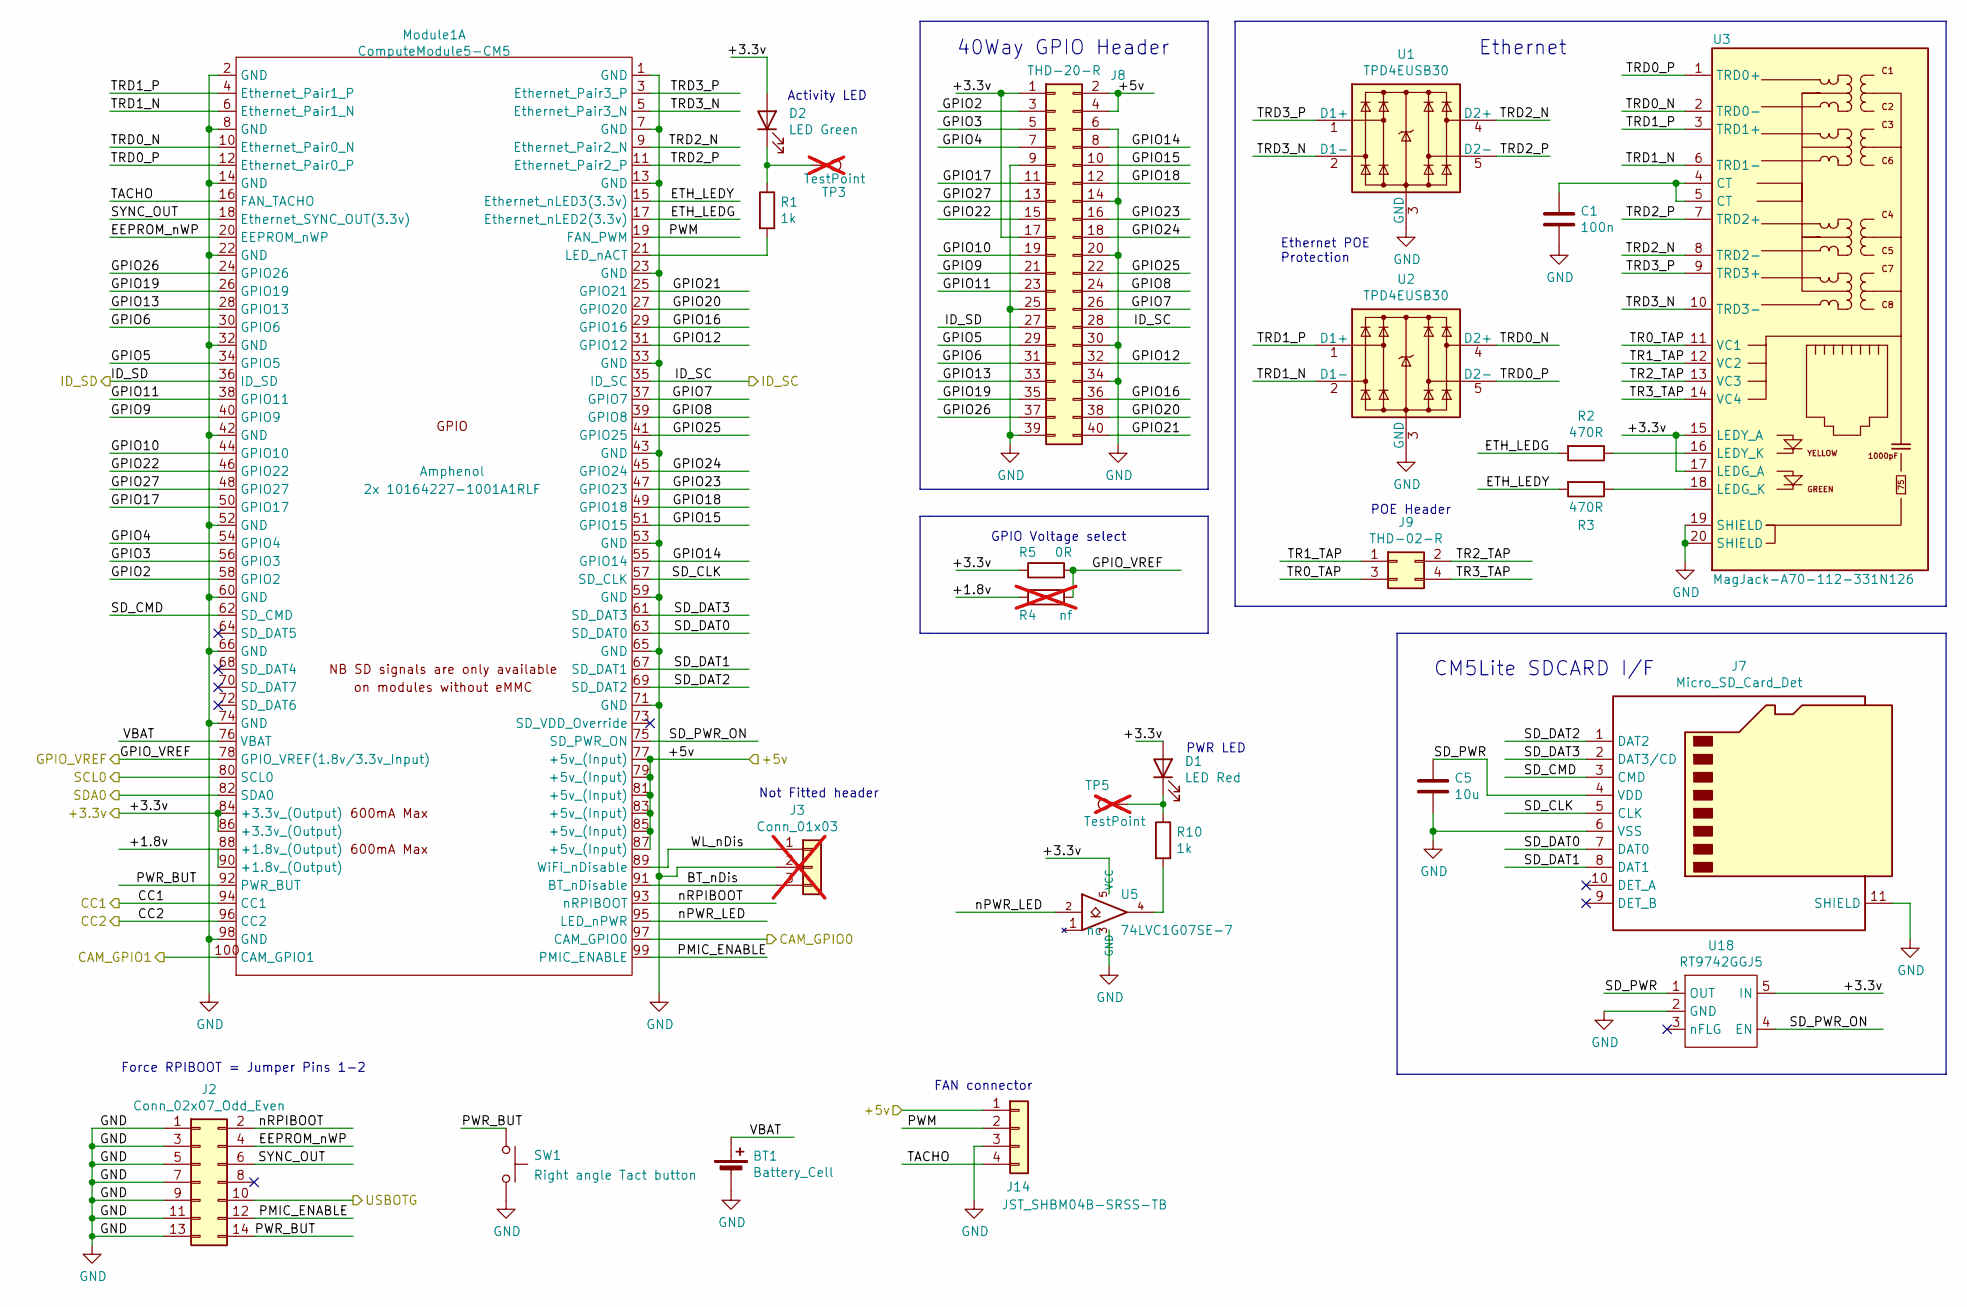
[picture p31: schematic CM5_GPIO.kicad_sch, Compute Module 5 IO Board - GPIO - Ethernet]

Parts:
BT1: Battery_Cell; BatteryHolder_Keystone_3034_1x20mm; Part Description Battery Retainer Coin, 20.0mm 1 Cell SM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
C1: 100n; C_0402_1005Metric; Part Description 0.1uF 10% 16V Ceramic Capacitor X7R 040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
C5: 10u; C_0805_2012Metric; Part Description 10uF 10% 10V Ceramic Capacitor X7R 0805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
D1: LED Red; LED_0603_1608Metric; Part Description Red 620nm LED Indication - Discrete 2.2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
D2: LED Green; LED_0603_1608Metric; Part Description Green 572nm LED Indication - Discrete 2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
J2: Conn_02x07_Odd_Even; PinHeader_2x07_P2.54mm_Vertical; Part Description PinHeader_2x07_P2.54mm_Vertical
J3: Conn_01x03; PinHeader_1x03_P2.54mm_Vertical; Part Description 3pin 0.1" connector; not fitted
J7: Micro_SD_Card_Det; SDCARD_MOLEX_503398-1892; Part Description 9 (8 + 1) Position Card Connector micro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
J8: THD-20-R; PinHeader_2x20_P2.54mm_Vertical; Part Description PinHeader_2x20_P2.54mm_Vertical
J9: THD-02-R; PinHeader_2x02_P2.54mm_Vertical; Part Description PinHeader_2x02_P2.54mm_Vertical
J14: JST_SHBM04B-SRSS-TB; JST_SH_BM04B-SRSS-TB_1x04-1MP_P1.00mm_Vertical; Part Description 4 pin vertical 1mm pitch connector
Module1: ComputeModule5-CM5; Raspberry-Pi-5-Compute-Module; Part Description 100 Position Connector Receptacle, Cent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
R1, R10: 1k; R_0402_1005Metric; Part Description Resistor 1K M1005 1% 63mW
R2, R3: 470R; R_0402_1005Metric; Part Description Resistor 470R M1005 1% 63mW
R4: nf; R_0805_2012Metric_Pad1.20x1.40mm_HandSolder; not fitted
R5: 0R; R_0805_2012Metric_Pad1.20x1.40mm_HandSolder; Part Description Resistor 0R M2012 5%
SW1: Right angle Tact button; SW_Tactile_SPST_Angled_PTS645Vx58-2LFS; Part Description Right angle through hole Tact switch
TP3, TP5: TestPoint; TestPoint_Pad_2.0x2.0mm; Part Description Test point; not fitted
U1, U2: TPD4EUSB30; USON-10_2.5x1.0mm_P0.5mm; Part Description Quad TVS diode for high speed signals (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
U3: MagJack-A70-112-331N126; TRJG0926HENL; Part Description Gigabit Ethernet Magjack
U5: 74LVC1G07SE-7; SOT-353_SC-70-5; Part Description Buffer, Non-Inverting 1 Element 1 Bit p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
U18: RT9742GGJ5; SOT-23-5; Part Description Power Switch/Driver 1:1 N-Channel 1A TS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

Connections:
/+3.3v: D1.2 (A), D2.2 (A), J8.1, J8.17, Module1.84 (+3.3v_(Output)), Module1.86 (+3.3v_(Output)), R5.1, U3.15 (LEDY_A), U3.17 (LEDG_A), U5.5 (VCC), U18.5 (IN); also elsewhere on the board
/+5v: J8.2, J8.4, J14.1, Module1.77 (+5v_(Input)), Module1.79 (+5v_(Input)), Module1.81 (+5v_(Input)), Module1.83 (+5v_(Input)), Module1.85 (+5v_(Input)), Module1.87 (+5v_(Input)); also elsewhere on the board
/CC1: Module1.94 (CC1); also elsewhere on the board
/CC2: Module1.96 (CC2); also elsewhere on the board
/CM5_GPIO ( Ethernet, GPIO, SDCARD)/+1.8v: Module1.88 (+1.8v_(Output)), Module1.90 (+1.8v_(Output)), R4.1
/CM5_GPIO ( Ethernet, GPIO, SDCARD)/BT_nDis: J3.3, Module1.91 (BT_nDisable)
/CM5_GPIO ( Ethernet, GPIO, SDCARD)/CAM_GPIO0: Module1.97 (CAM_GPIO0); also elsewhere on the board
/CM5_GPIO ( Ethernet, GPIO, SDCARD)/CAM_GPIO1: Module1.100 (CAM_GPIO1); also elsewhere on the board
/CM5_GPIO ( Ethernet, GPIO, SDCARD)/EEPROM_nWP: J2.4, Module1.20 (EEPROM_nWP)
/CM5_GPIO ( Ethernet, GPIO, SDCARD)/ETH_LEDG: Module1.17 (Ethernet_nLED2(3.3v)), R2.2
/CM5_GPIO ( Ethernet, GPIO, SDCARD)/ETH_LEDY: Module1.15 (Ethernet_nLED3(3.3v)), R3.2
/CM5_GPIO ( Ethernet, GPIO, SDCARD)/GPIO2: J8.3, Module1.58 (GPIO2)
/CM5_GPIO ( Ethernet, GPIO, SDCARD)/GPIO3: J8.5, Module1.56 (GPIO3)
/CM5_GPIO ( Ethernet, GPIO, SDCARD)/GPIO4: J8.7, Module1.54 (GPIO4)
/CM5_GPIO ( Ethernet, GPIO, SDCARD)/GPIO5: J8.29, Module1.34 (GPIO5)
/CM5_GPIO ( Ethernet, GPIO, SDCARD)/GPIO6: J8.31, Module1.30 (GPIO6)
/CM5_GPIO ( Ethernet, GPIO, SDCARD)/GPIO7: J8.26, Module1.37 (GPIO7)
/CM5_GPIO ( Ethernet, GPIO, SDCARD)/GPIO8: J8.24, Module1.39 (GPIO8)
/CM5_GPIO ( Ethernet, GPIO, SDCARD)/GPIO9: J8.21, Module1.40 (GPIO9)
/CM5_GPIO ( Ethernet, GPIO, SDCARD)/GPIO10: J8.19, Module1.44 (GPIO10)
/CM5_GPIO ( Ethernet, GPIO, SDCARD)/GPIO11: J8.23, Module1.38 (GPIO11)
/CM5_GPIO ( Ethernet, GPIO, SDCARD)/GPIO12: J8.32, Module1.31 (GPIO12)
/CM5_GPIO ( Ethernet, GPIO, SDCARD)/GPIO13: J8.33, Module1.28 (GPIO13)
/CM5_GPIO ( Ethernet, GPIO, SDCARD)/GPIO14: J8.8, Module1.55 (GPIO14)
/CM5_GPIO ( Ethernet, GPIO, SDCARD)/GPIO15: J8.10, Module1.51 (GPIO15)
/CM5_GPIO ( Ethernet, GPIO, SDCARD)/GPIO16: J8.36, Module1.29 (GPIO16)
/CM5_GPIO ( Ethernet, GPIO, SDCARD)/GPIO17: J8.11, Module1.50 (GPIO17)
/CM5_GPIO ( Ethernet, GPIO, SDCARD)/GPIO18: J8.12, Module1.49 (GPIO18)
/CM5_GPIO ( Ethernet, GPIO, SDCARD)/GPIO19: J8.35, Module1.26 (GPIO19)
/CM5_GPIO ( Ethernet, GPIO, SDCARD)/GPIO20: J8.38, Module1.27 (GPIO20)
/CM5_GPIO ( Ethernet, GPIO, SDCARD)/GPIO21: J8.40, Module1.25 (GPIO21)
/CM5_GPIO ( Ethernet, GPIO, SDCARD)/GPIO22: J8.15, Module1.46 (GPIO22)
/CM5_GPIO ( Ethernet, GPIO, SDCARD)/GPIO23: J8.16, Module1.47 (GPIO23)
/CM5_GPIO ( Ethernet, GPIO, SDCARD)/GPIO24: J8.18, Module1.45 (GPIO24)
/CM5_GPIO ( Ethernet, GPIO, SDCARD)/GPIO25: J8.22, Module1.41 (GPIO25)
/CM5_GPIO ( Ethernet, GPIO, SDCARD)/GPIO26: J8.37, Module1.24 (GPIO26)
/CM5_GPIO ( Ethernet, GPIO, SDCARD)/GPIO27: J8.13, Module1.48 (GPIO27)
/CM5_GPIO ( Ethernet, GPIO, SDCARD)/GPIO_VREF: Module1.78 (GPIO_VREF(1.8v/3.3v_Input)), R4.2, R5.2; also elsewhere on the board
/CM5_GPIO ( Ethernet, GPIO, SDCARD)/ID_SC: J8.28, Module1.35 (ID_SC); also elsewhere on the board
/CM5_GPIO ( Ethernet, GPIO, SDCARD)/ID_SD: J8.27, Module1.36 (ID_SD); also elsewhere on the board
/CM5_GPIO ( Ethernet, GPIO, SDCARD)/PMIC_ENABLE: J2.12, Module1.99 (PMIC_ENABLE)
/CM5_GPIO ( Ethernet, GPIO, SDCARD)/PWM: J14.2, Module1.19 (FAN_PWM)
/CM5_GPIO ( Ethernet, GPIO, SDCARD)/PWR_BUT: J2.14, Module1.92 (PWR_BUT), SW1.1
/CM5_GPIO ( Ethernet, GPIO, SDCARD)/SD_CLK: J7.5 (CLK), Module1.57 (SD_CLK)
/CM5_GPIO ( Ethernet, GPIO, SDCARD)/SD_CMD: J7.3 (CMD), Module1.62 (SD_CMD)
/CM5_GPIO ( Ethernet, GPIO, SDCARD)/SD_DAT0: J7.7 (DAT0), Module1.63 (SD_DAT0)
/CM5_GPIO ( Ethernet, GPIO, SDCARD)/SD_DAT1: J7.8 (DAT1), Module1.67 (SD_DAT1)
/CM5_GPIO ( Ethernet, GPIO, SDCARD)/SD_DAT2: J7.1 (DAT2), Module1.69 (SD_DAT2)
/CM5_GPIO ( Ethernet, GPIO, SDCARD)/SD_DAT3: J7.2 (DAT3/CD), Module1.61 (SD_DAT3)
/CM5_GPIO ( Ethernet, GPIO, SDCARD)/SD_PWR: C5.1, J7.4 (VDD), U18.1 (OUT)
/CM5_GPIO ( Ethernet, GPIO, SDCARD)/SD_PWR_ON: Module1.75 (SD_PWR_ON), U18.4 (EN)
/CM5_GPIO ( Ethernet, GPIO, SDCARD)/SYNC_OUT: J2.6, Module1.18 (Ethernet_SYNC_OUT(1.8v))
/CM5_GPIO ( Ethernet, GPIO, SDCARD)/TACHO: J14.4, Module1.16 (FAN_TACHO)
/CM5_GPIO ( Ethernet, GPIO, SDCARD)/TR0_TAP: J9.3, U3.11 (VC1)
/CM5_GPIO ( Ethernet, GPIO, SDCARD)/TR1_TAP: J9.1, U3.12 (VC2)
/CM5_GPIO ( Ethernet, GPIO, SDCARD)/TR2_TAP: J9.2, U3.13 (VC3)
/CM5_GPIO ( Ethernet, GPIO, SDCARD)/TR3_TAP: J9.4, U3.14 (VC4)
/CM5_GPIO ( Ethernet, GPIO, SDCARD)/TRD0_N: Module1.10 (Ethernet_Pair0_N), U2.4 (D2+), U2.7, U3.2 (TRD0-)
/CM5_GPIO ( Ethernet, GPIO, SDCARD)/TRD0_P: Module1.12 (Ethernet_Pair0_P), U2.5 (D2-), U2.6, U3.1 (TRD0+)
/CM5_GPIO ( Ethernet, GPIO, SDCARD)/TRD1_N: Module1.6 (Ethernet_Pair1_N), U2.2 (D1-), U2.9, U3.6 (TRD1-)
/CM5_GPIO ( Ethernet, GPIO, SDCARD)/TRD1_P: Module1.4 (Ethernet_Pair1_P), U2.1 (D1+), U2.10, U3.3 (TRD1+)
/CM5_GPIO ( Ethernet, GPIO, SDCARD)/TRD2_N: Module1.9 (Ethernet_Pair2_N), U1.4 (D2+), U1.7, U3.8 (TRD2-)
/CM5_GPIO ( Ethernet, GPIO, SDCARD)/TRD2_P: Module1.11 (Ethernet_Pair2_P), U1.5 (D2-), U1.6, U3.7 (TRD2+)
/CM5_GPIO ( Ethernet, GPIO, SDCARD)/TRD3_N: Module1.5 (Ethernet_Pair3_N), U1.2 (D1-), U1.9, U3.10 (TRD3-)
/CM5_GPIO ( Ethernet, GPIO, SDCARD)/TRD3_P: Module1.3 (Ethernet_Pair3_P), U1.1 (D1+), U1.10, U3.9 (TRD3+)
/CM5_GPIO ( Ethernet, GPIO, SDCARD)/USBOTG: J2.10; also elsewhere on the board
/CM5_GPIO ( Ethernet, GPIO, SDCARD)/VBAT: BT1.1 (+), Module1.76 (VBAT)
/CM5_GPIO ( Ethernet, GPIO, SDCARD)/WL_nDis: J3.1, Module1.89 (WiFi_nDisable)
/CM5_GPIO ( Ethernet, GPIO, SDCARD)/nPWR_LED: Module1.95 (LED_nPWR), U5.2
/CM5_GPIO ( Ethernet, GPIO, SDCARD)/nRPIBOOT: J2.2, Module1.93 (nRPIBOOT)
/CM5_HighSpeed/SCL0: Module1.80 (SCL0); also elsewhere on the board
/CM5_HighSpeed/SDA0: Module1.82 (SDA0); also elsewhere on the board
GND: BT1.2 (-), C1.2, C5.2, J2.1, J2.3, J2.5, J2.7, J2.9, J2.11, J2.13, J3.2, J7.6 (VSS), J7.11 (SHIELD), J8.6, J8.9, J8.14, J8.20, J8.25, J8.30, J8.34, J8.39, J14.3, Module1.1 (GND), Module1.2 (GND), Module1.7 (GND), Module1.8 (GND), Module1.13 (GND), Module1.14 (GND), Module1.22 (GND), Module1.23 (GND), Module1.32 (GND), Module1.33 (GND), Module1.42 (GND), Module1.43 (GND), Module1.52 (GND), Module1.53 (GND), Module1.59 (GND), Module1.60 (GND), Module1.65 (GND), Module1.66 (GND), Module1.71 (GND), Module1.74 (GND), Module1.98 (GND), SW1.2, U1.3 (GND), U1.8 (GND), U2.3 (GND), U2.8 (GND), U3.19 (SHIELD), U3.20 (SHIELD), U5.3 (GND), U18.2 (GND); also elsewhere on the board
unnamed: C1.1, U3.4 (CT), U3.5 (CT)
unnamed: D1.1 (K), R10.1, TP5.1
unnamed: D2.1 (K), R1.1, TP3.1
unnamed: Module1.21 (LED_nACT), R1.2
unnamed: R10.2, U5.4
unnamed: R3.1, U3.18 (LEDG_K)
unnamed: R2.1, U3.16 (LEDY_K)

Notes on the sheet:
40Way GPIO Header
Activity LED
FAN connector
Ethernet POE Protection
GPIO Voltage select
Not Fitted header
POE Header
Force RPIBOOT = Jumper Pins 1-2
PWR LED
Ethernet
CM5Lite SDCARD I/F


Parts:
C2, C7, C8: 10u; C_0805_2012Metric; Part Description 10uF 10% 10V Ceramic Capacitor X7R 0805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
C3: 100uF; CP_EIA-7343-31_Kemet-D; Part Description Capacitor, SP-Cap, 100u, 6.3V, 15mR ESR
C12, C13: 100n; C_0402_1005Metric; Part Description 0.1uF 10% 16V Ceramic Capacitor X7R 040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
J5, J16: Conn_01x22_Female; Hirose_FH12-22S-0.5SH_1x22-1MP_P0.50mm_Horizontal; Part Description 22 Position FFC, FPC Connector Contacts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
J6: THD-02-R; PinHeader_2x02_P2.54mm_Vertical; Part Description PinHeader_2x02_P2.54mm_Vertical
J10, J22: 690-019-298-412; EDAC 690-019-298-412; Part Description HDMI Connector, Right Angle, 19 Contact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
J12: USB3_A; MTCONN_UBAF30-D2011; Part Description Dual USB 3 connector
Module1: ComputeModule5-CM5; Raspberry-Pi-5-Compute-Module; Part Description 100 Position Connector Receptacle, Cent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
R6, R7, R8: 2.2K 1%; R_0402_1005Metric; Part Description Resistor 2.2K M1005 1% 63mW
R12: 15K 1%; R_0402_1005Metric; Part Description Resistor 15K M1005 1% 63mW
U6: AP22653W6; SOT-23-6; Part Description Power Switch/Driver 1:1 P-Channel 2.1A 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
U12: RT9742SNGV; TSOT-23_HandSoldering; Part Description Power Switch/Driver 1:1 N-Channel 500mA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

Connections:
/+3.3v: J5.22, J16.22, R8.1; also elsewhere on the board
/+5v: C2.1, C12.1, U6.1 (IN), U12.1 (IN); also elsewhere on the board
/CM5_GPIO ( Ethernet, GPIO, SDCARD)/CAM_GPIO0: J5.17; also elsewhere on the board
/CM5_GPIO ( Ethernet, GPIO, SDCARD)/CAM_GPIO1: J5.18; also elsewhere on the board
/CM5_GPIO ( Ethernet, GPIO, SDCARD)/GPIO_VREF: R6.1, R7.1; also elsewhere on the board
/CM5_GPIO ( Ethernet, GPIO, SDCARD)/ID_SC: J6.1; also elsewhere on the board
/CM5_GPIO ( Ethernet, GPIO, SDCARD)/ID_SD: J6.3; also elsewhere on the board
/CM5_GPIO ( Ethernet, GPIO, SDCARD)/USBOTG: Module1.101 (USB_OTG_ID); also elsewhere on the board
/CM5_HighSpeed/DPHY0_C_N: J5.8, Module1.127 (DPHY0_C_N)
/CM5_HighSpeed/DPHY0_C_P: J5.9, Module1.129 (DPHY0_C_P)
/CM5_HighSpeed/DPHY0_D0_N: J5.2, Module1.115 (DPHY0_D0_N)
/CM5_HighSpeed/DPHY0_D0_P: J5.3, Module1.117 (DPHY0_D0_P)
/CM5_HighSpeed/DPHY0_D1_N: J5.5, Module1.121 (DPHY0_D1_N)
/CM5_HighSpeed/DPHY0_D1_P: J5.6, Module1.123 (DPHY0_D1_P)
/CM5_HighSpeed/DPHY0_D2_N: J5.11, Module1.133 (DPHY0_D2_N)
/CM5_HighSpeed/DPHY0_D2_P: J5.12, Module1.135 (DPHY0_D2_P)
/CM5_HighSpeed/DPHY0_D3_N: J5.14, Module1.139 (DPHY0_D3_N)
/CM5_HighSpeed/DPHY0_D3_P: J5.15, Module1.141 (DPHY0_D3_P)
/CM5_HighSpeed/DPHY1_C_N: J16.8, Module1.187 (DPHY1_C_N)
/CM5_HighSpeed/DPHY1_C_P: J16.9, Module1.189 (DPHY1_C_P)
/CM5_HighSpeed/DPHY1_D0_N: J16.2, Module1.175 (DPHY1_D0_N)
/CM5_HighSpeed/DPHY1_D0_P: J16.3, Module1.177 (DPHY1_D0_P)
/CM5_HighSpeed/DPHY1_D1_N: J16.5, Module1.181 (DPHY1_D1_N)
/CM5_HighSpeed/DPHY1_D1_P: J16.6, Module1.183 (DPHY1_D1_P)
/CM5_HighSpeed/DPHY1_D2_N: J16.11, Module1.193 (DPHY1_D2_N)
/CM5_HighSpeed/DPHY1_D2_P: J16.12, Module1.195 (DPHY1_D2_P)
/CM5_HighSpeed/DPHY1_D3_N: J16.14, Module1.194 (DPHY1_D3_N)
/CM5_HighSpeed/DPHY1_D3_P: J16.15, Module1.196 (DPHY1_D3_P)
/CM5_HighSpeed/HDMI0_CEC: J22.13 (CEC), Module1.151 (HDMI0_CEC)
/CM5_HighSpeed/HDMI0_CK_N: J22.12 (CK-), Module1.190 (HDMI0_CLK_N)
/CM5_HighSpeed/HDMI0_CK_P: J22.10 (CK+), Module1.188 (HDMI0_CLK_P)
/CM5_HighSpeed/HDMI0_D0_N: J22.9 (D0-), Module1.184 (HDMI0_TX0_N)
/CM5_HighSpeed/HDMI0_D0_P: J22.7 (D0+), Module1.182 (HDMI0_TX0_P)
/CM5_HighSpeed/HDMI0_D1_N: J22.6 (D1-), Module1.178 (HDMI0_TX1_N)
/CM5_HighSpeed/HDMI0_D1_P: J22.4 (D1+), Module1.176 (HDMI0_TX1_P)
/CM5_HighSpeed/HDMI0_D2_N: J22.3 (D2-), Module1.172 (HDMI0_TX2_N)
/CM5_HighSpeed/HDMI0_D2_P: J22.1 (D2+), Module1.170 (HDMI0_TX2_P)
/CM5_HighSpeed/HDMI0_HOTPLUG: J22.19 (HPD/HEAC-), Module1.153 (HDMI0_HOTPLUG)
/CM5_HighSpeed/HDMI0_SCL: J22.15 (SCL), Module1.200 (HDMI0_SCL)
/CM5_HighSpeed/HDMI0_SDA: J22.16 (SDA), Module1.199 (HDMI0_SDA)
/CM5_HighSpeed/HDMI1_CEC: J10.13 (CEC), Module1.149 (HDMI1_CEC)
/CM5_HighSpeed/HDMI1_CK_N: J10.12 (CK-), Module1.166 (HDMI1_CLK_N)
/CM5_HighSpeed/HDMI1_CK_P: J10.10 (CK+), Module1.164 (HDMI1_CLK_P)
/CM5_HighSpeed/HDMI1_D0_N: J10.9 (D0-), Module1.160 (HDMI1_TX0_N)
/CM5_HighSpeed/HDMI1_D0_P: J10.7 (D0+), Module1.158 (HDMI1_TX0_P)
/CM5_HighSpeed/HDMI1_D1_N: J10.6 (D1-), Module1.154 (HDMI1_TX1_N)
/CM5_HighSpeed/HDMI1_D1_P: J10.4 (D1+), Module1.152 (HDMI1_TX1_P)
/CM5_HighSpeed/HDMI1_D2_N: J10.3 (D2-), Module1.148 (HDMI1_TX2_N)
/CM5_HighSpeed/HDMI1_D2_P: J10.1 (D2+), Module1.146 (HDMI1_TX2_P)
/CM5_HighSpeed/HDMI1_HOTPLUG: J10.19 (HPD/HEAC-), Module1.143 (HDMI1_HOTPLUG)
/CM5_HighSpeed/HDMI1_SCL: J10.15 (SCL), Module1.147 (HDMI1_SCL)
/CM5_HighSpeed/HDMI1_SDA: J10.16 (SDA), Module1.145 (HDMI1_SDA)
/CM5_HighSpeed/HDMI_5v: C13.1, J10.18 (+5V), J22.18 (+5V), U12.2 (OUT)
/CM5_HighSpeed/PCIE_CLK_N: Module1.112 (PCIe_CLK_N); also elsewhere on the board
/CM5_HighSpeed/PCIE_CLK_P: Module1.110 (PCIe_CLK_P); also elsewhere on the board
/CM5_HighSpeed/PCIE_PWR_EN: Module1.106 (PCIE_PWR_EN); also elsewhere on the board
/CM5_HighSpeed/PCIE_RX_N: Module1.118 (PCIe_RX_N); also elsewhere on the board
/CM5_HighSpeed/PCIE_RX_P: Module1.116 (PCIe_RX_P); also elsewhere on the board
/CM5_HighSpeed/PCIE_TX_N: Module1.124 (PCIe_TX_N); also elsewhere on the board
/CM5_HighSpeed/PCIE_TX_P: Module1.122 (PCIe_TX_P); also elsewhere on the board
/CM5_HighSpeed/PCIE_nCLKREQ: Module1.102 (PCIe_nCLKREQ); also elsewhere on the board
/CM5_HighSpeed/PCIE_nRST: Module1.109 (PCIe_nRST); also elsewhere on the board
/CM5_HighSpeed/PCIE_nWAKE: Module1.104 (PCIE_nWAKE); also elsewhere on the board
/CM5_HighSpeed/SCL0: J5.20; also elsewhere on the board
/CM5_HighSpeed/SCL1: J6.2, J16.20, R7.2
/CM5_HighSpeed/SDA0: J5.21; also elsewhere on the board
/CM5_HighSpeed/SDA1: J6.4, J16.21, R6.2
/CM5_HighSpeed/USB3-0-D_N: J12.A2 (D-), Module1.136 (USB3-0-D_N)
/CM5_HighSpeed/USB3-0-D_P: J12.A3 (D+), Module1.134 (USB3-0-D_P)
/CM5_HighSpeed/USB3-0-RX_N: J12.A6 (SSRX+), Module1.128 (USB3-0-RX_N)
/CM5_HighSpeed/USB3-0-RX_P: J12.A5 (SSRX-), Module1.130 (USB3-0-RX_P)
/CM5_HighSpeed/USB3-0-TX_N: J12.A9 (SSTX+), Module1.140 (USB3-0-TX_N)
/CM5_HighSpeed/USB3-0-TX_P: J12.A8 (SSTX-), Module1.142 (USB3-0-TX_P)
/CM5_HighSpeed/USB3-1-D_N: J12.B2 (D-), Module1.165 (USB3-1-D_N)
/CM5_HighSpeed/USB3-1-D_P: J12.B3 (D+), Module1.163 (USB3-1-D_P)
/CM5_HighSpeed/USB3-1-RX_N: J12.B6 (SSRX+), Module1.157 (USB3-1-RX_N)
/CM5_HighSpeed/USB3-1-RX_P: J12.B5 (SSRX-), Module1.159 (USB3-1-RX_P)
/CM5_HighSpeed/USB3-1-TX_N: J12.B9 (SSTX+), Module1.169 (USB3-1-TX_N)
/CM5_HighSpeed/USB3-1-TX_P: J12.B8 (SSTX-), Module1.171 (USB3-1-TX_P)
/CM5_HighSpeed/VBUS: C3.1, C7.1, C8.1, J12.A1 (VBUS), J12.B1 (VBUS), U6.6 (OUT)
/CM5_HighSpeed/VBUS_EN: Module1.111 (VBUS_EN), U6.3 (EN)
/USB2_N: Module1.103 (USB2_N); also elsewhere on the board
/USB2_P: Module1.105 (USB2_P); also elsewhere on the board
GND: C2.2, C3.2, C7.2, C8.2, C12.2, C13.2, J5.1, J5.4, J5.7, J5.10, J5.13, J5.16, J5.19, J10.2 (D2S), J10.5 (D1S), J10.8 (D0S), J10.11 (CKS), J10.17 (GND), J10.SH1 (SH), J10.SH2 (SH), J10.SH3 (SH), J10.SH4 (SH), J12.10 (SHIELD), J12.A4 (GND), J12.A7 (DRAIN), J12.B4 (GND), J12.B7 (DRAIN), J16.1, J16.4, J16.7, J16.10, J16.13, J16.16, J16.19, J22.2 (D2S), J22.5 (D1S), J22.8 (D0S), J22.11 (CKS), J22.17 (GND), J22.SH1 (SH), J22.SH2 (SH), J22.SH3 (SH), J22.SH4 (SH), Module1.107 (GND), Module1.108 (GND), Module1.113 (GND), Module1.114 (GND), Module1.119 (GND), Module1.120 (GND), Module1.125 (GND), Module1.126 (GND), Module1.131 (GND), Module1.132 (GND), Module1.137 (GND), Module1.138 (GND), Module1.144 (GND), Module1.150 (GND), Module1.155 (GND), Module1.156 (GND), Module1.161 (GND), Module1.162 (GND), Module1.167 (GND), Module1.168 (GND), Module1.173 (GND), Module1.174 (GND), Module1.179 (GND), Module1.180 (GND), Module1.185 (GND), Module1.186 (GND), Module1.191 (GND), Module1.192 (GND), Module1.197 (GND), Module1.198 (GND), R12.2, U6.2 (GND), U12.3 (GND); also elsewhere on the board
unnamed: J16.17, R8.2
unnamed: R12.1, U6.5 (ILIM)

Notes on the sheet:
USB 3 Pairs P/N swapped to help routing
Jumpers to be fitted if DPHY1 is used
Current Limit switch
DSI/CSI Connectors
Stacked USB connectors

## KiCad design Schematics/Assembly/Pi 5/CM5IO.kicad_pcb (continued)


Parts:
C4, C6, C14, C15, C16, C17: 10u; C_0805_2012Metric; Part Description 10uF 10% 10V Ceramic Capacitor X7R 0805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
C10, C19: 100n; C_0402_1005Metric; Part Description 0.1uF 10% 16V Ceramic Capacitor X7R 040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
C11: 4.7nF; C_0402_1005Metric; Part Description 4.7nF capacitor 0402
D3: LED Green; LED_0603_1608Metric; Part Description Green 572nm LED Indication - Discrete 2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
J4: Bus_M.2_Socket_M; M.2 M Key socket; Part Description M.2 M Key connector
L1: 2.2uH; L_Bourns_SRP5030CC; Part Description Inductor, SMT, 2520, 2u2, IRMS=7A, ISAT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
M1: M.2 Screw; Part Description M.2 Screw
M2, M3, M4, M5: M.2 Solder Nut; Part Description Solder nut for M.2 slot
R14: 100K 1%; R_0402_1005Metric; Part Description Resistor 100K M1005 1% 63mW
R15: 10K 1%; R_0402_1005Metric; Part Description Resistor 10K M1005 1% 63mW
R16: 2.2K 1%; R_0402_1005Metric; Part Description Resistor 2.2K M1005 1% 63mW
R17: 1k; R_0402_1005Metric; Part Description Resistor 1K M1005 1% 63mW
TP1: TestPoint; TestPoint_Pad_2.0x2.0mm; Part Description Test point; not fitted
U7: ASEK-32.768KHZ-L-R-T; Crystal_SMD_3225-4Pin_3.2x2.5mm; Part Description 32KHz Xtal oscilator
U8: AP3441SHE-7B; DFN-8-1EP_2x2mm_P0.5mm_EP1.05x1.75mm; Part Description 3A DC-DC converter

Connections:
/+5v: C4.1, C6.1, C10.1, U8.3 (VIN); also elsewhere on the board
/CM5_HighSpeed/PCIE_CLK_N: J4.53 (REFCLKn); also elsewhere on the board
/CM5_HighSpeed/PCIE_CLK_P: J4.55 (REFCLKp); also elsewhere on the board
/CM5_HighSpeed/PCIE_PWR_EN: R14.1, U8.7 (EN); also elsewhere on the board
/CM5_HighSpeed/PCIE_RX_N: J4.43 (PETp0); also elsewhere on the board
/CM5_HighSpeed/PCIE_RX_P: J4.41 (PETn0); also elsewhere on the board
/CM5_HighSpeed/PCIE_TX_N: J4.49 (PERp0); also elsewhere on the board
/CM5_HighSpeed/PCIE_TX_P: J4.47 (PERn0); also elsewhere on the board
/CM5_HighSpeed/PCIE_nCLKREQ: J4.52 (~CLKREQ); also elsewhere on the board
/CM5_HighSpeed/PCIE_nRST: J4.50 (~PERST); also elsewhere on the board
/CM5_HighSpeed/PCIE_nWAKE: J4.54 (~PEWAKE); also elsewhere on the board
/PCIe-M2/FB: C11.2, R15.2, R16.1, U8.1 (FB)
/PCIe-M2/M2_3v3: C11.1, C14.1, C15.1, C16.1, C17.1, C19.1, D3.2 (A), J4.2 (3.3V), J4.4 (3.3V), J4.12 (3.3V), J4.14 (3.3V), J4.16 (3.3V), J4.18 (3.3V), J4.70 (3.3V), J4.72 (3.3V), J4.74 (3.3V), L1.2, R15.1, U7.1 (EN), U7.4 (VDD)
GND: C4.2, C6.2, C10.2, C14.2, C15.2, C16.2, C17.2, C19.2, J4.1 (GND), J4.3 (GND), J4.9 (GND), J4.15 (GND), J4.21 (GND), J4.27 (GND), J4.33 (GND), J4.39 (GND), J4.45 (GND), J4.51 (GND), J4.57 (GND), J4.71 (GND), J4.73 (GND), J4.75 (GND), J4.M1 (GND2230), J4.M2 (GND2242), J4.M3 (GND2260), J4.M4 (GND2280), J4.S1, J4.S2, R14.2, R16.2, U7.2 (GND), U8.4 (PGND), U8.8 (SGND), U8.9 (PAD); also elsewhere on the board
unnamed: D3.1 (K), R17.1, TP1.1
unnamed: J4.10 (DAS/~DSS/~LED1), R17.2
unnamed: J4.68 (SUSCLK), U7.3 (Out)
unnamed: L1.1, U8.6 (LX)

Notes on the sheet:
Activity LED

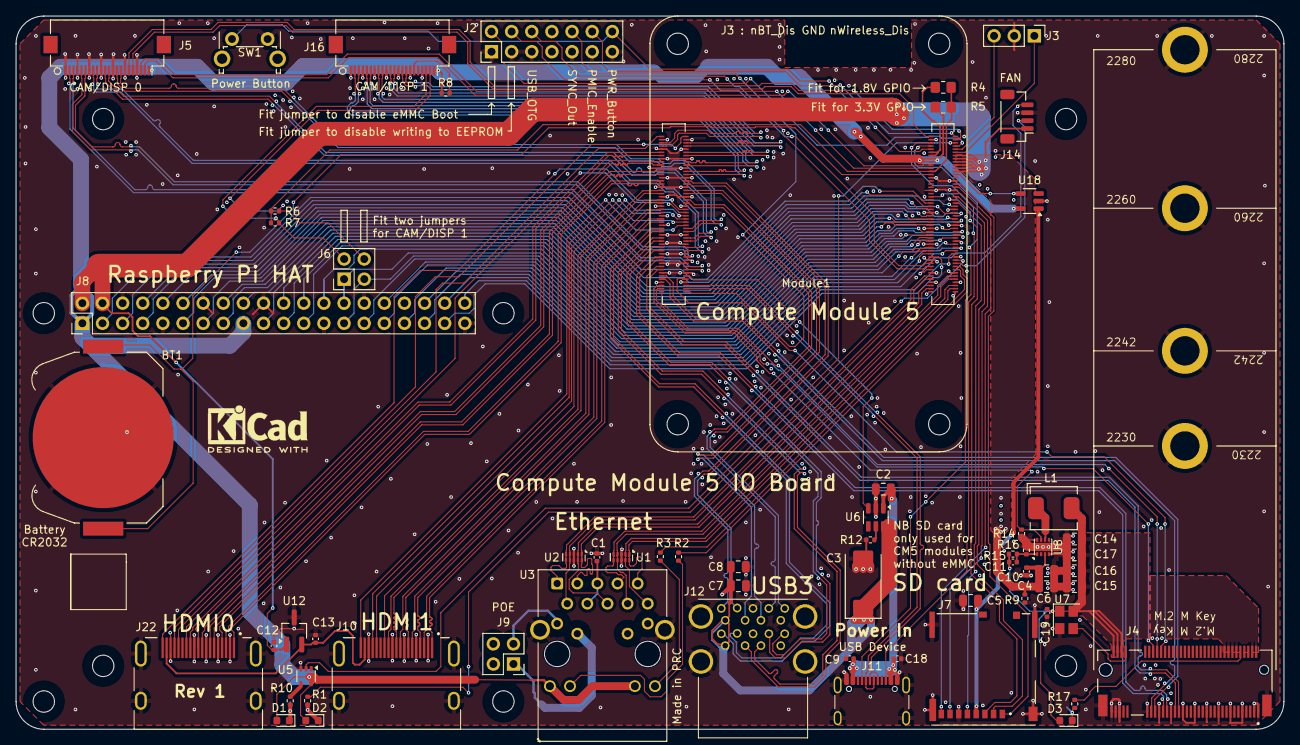
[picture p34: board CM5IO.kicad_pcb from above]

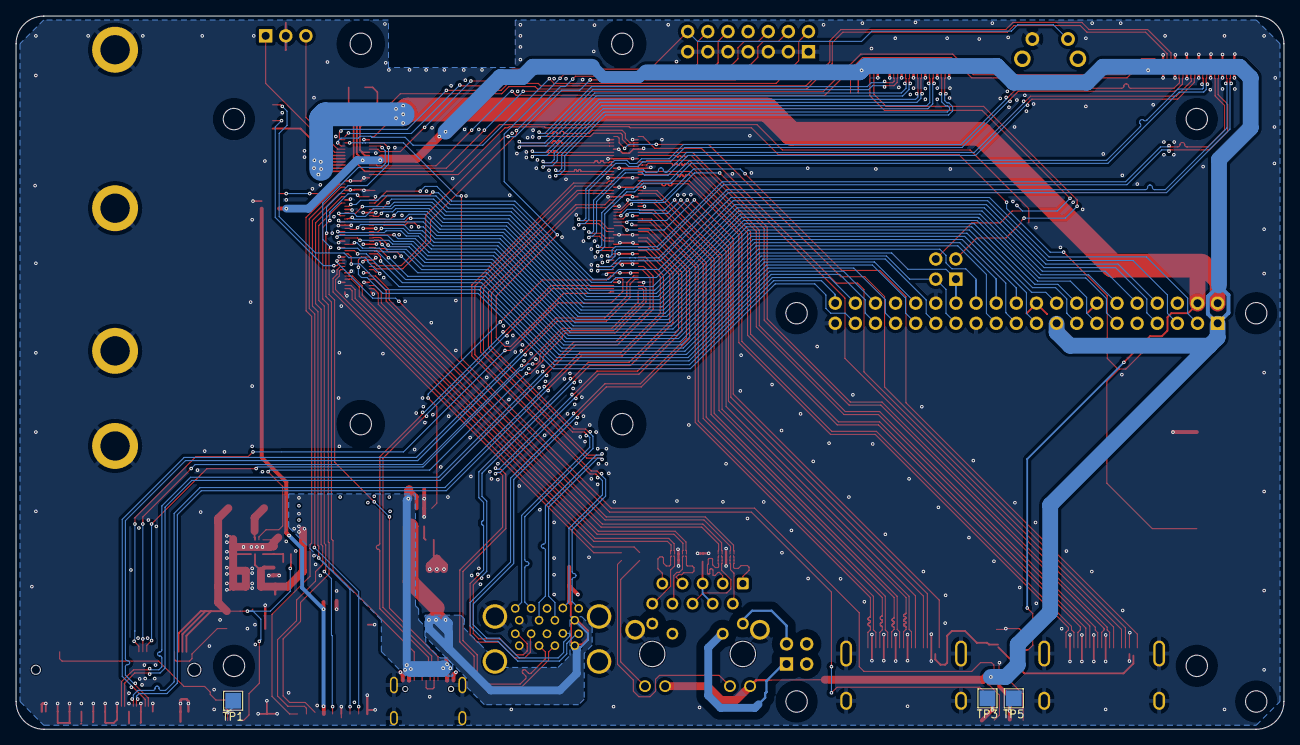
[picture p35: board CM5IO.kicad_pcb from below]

Board: 4 copper layers, 160.0 x 90.0 mm, 76 parts (3 on the bottom side), 161 nets.

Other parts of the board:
logo1: KiCad-Logo2_5mm_SilkScreen

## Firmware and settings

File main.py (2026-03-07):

#! /usr/bin/env python3

import sys
import sqlite3
import logging
import socket
from enum import Enum
from csv import writer
from datetime import datetime, timedelta
from typing import Any, Optional
from PyQt6.QtGui import QColor, QPixmap
from PyQt6.QtCore import Qt, QTimer
from PyQt6.QtWidgets import QWidget
from gpiozero import DigitalInputDevice, LED
from PyQt6.QtWidgets import QApplication, QMainWindow
from MainWindow import Ui_MainWindow
from pathlib import Path
from Product import Product
from Count import Count
from SharepointExport import SharepointExport

class ExportBackend(Enum):
    NONE = 0
    FOLDER = 1
    SHAREPOINT = 2

class OperationMode(Enum):
    COUNT = 0
    TARGET = 1
    REJECT = 2
    PACE = 3
    DOUBLE = 4

class OperationState(Enum):
    NORMAL = 0
    WARNING = 1
    FAULT = 2

class ObjectCounter(QMainWindow, Ui_MainWindow):
    def __init__(self, parent: Optional[QWidget] = None):
        super().__init__(parent)
        self.logger = logging.getLogger(__name__)
        self.root_dir = Path(__file__).parent
        Path('./logs/').mkdir(parents=True, exist_ok=True)
        logging.basicConfig(filename='./logs/.counter_debug_' + datetime.now().strftime('%Y-%m-%d_%H-%M') + '.log', level=logging.DEBUG)
        self.logger.info('Started Program')
        self.setupUi(self) # pyright: ignore[reportUnknownMemberType]

        self.current_good: int = 0
        self.current_reject: int = 0
        self.all_products: list[Product] = []
        self.loaded_product: Product | None = None
        self.selected_product: Product | None = None
        self.last_count_1: Count | None = None
        self.last_count_2: Count | None = None
        self.count_list_1: list[Count] = []
        self.count_list_2: list[Count] = []
        self.quality_percent: float = 0
        self.current_ppm_1: float = 0
        self.current_ppm_2: float = 0
        self.current_ppm_delta_1: float = 0
        self.current_ppm_delta_2: float = 0
        self.is_logged_in: bool = False
        self.is_fullscreen: bool = True
        self.is_runing_exports_01: bool = False
        self.is_runing_exports_02: bool = False
        self.export_01_timer: QTimer = QTimer()
        self.export_02_timer: QTimer = QTimer()
        self.is_export_setup: bool = False
        self.sharepoint_export: Optional[SharepointExport] = None
        self.current_operation_state: int = OperationState.FAULT.value

        self.operation_mode: int = 0
        self.is_reject_enabled: bool = False
        self.bounce_time: float = 0.1
        self.infeed_pin: int = 17
        self.outfeed_pin: int = 23
        self.stack_pin_green: int = 27
        self.stack_pin_yellow: int = 22
        self.stack_pin_red: int = 24
        self.machine_name: str = "SampleMachine"
        self.export_backend: int = 0
        self.is_export_folder_01_enabled: bool = False
        self.is_export_folder_02_enabled: bool = False
        self.is_export_single_file_enabled: bool = False
        self.export_folder_01_path: str = ""
        self.export_folder_02_path: str = ""
        self.export_folder_01_frequency: int = 1
        self.export_folder_02_frequency: int = 1
        self.export_folder_01_period: int = 1
        self.export_folder_02_period: int = 1
        self.is_export_sharepoint_01_enabled: bool = False
        self.is_export_sharepoint_02_enabled: bool = False
        self.export_sharepoint_01_frequency: int = 1
        self.export_sharepoint_02_frequency: int = 1
        self.export_sharepoint_01_period: int = 1
        self.export_sharepoint_02_period: int = 1
        self.export_sharepoint_01_site_id: str = ""
        self.export_sharepoint_02_site_id: str = ""
        self.export_sharepoint_01_list_id: str = ""
        self.export_sharepoint_02_list_id: str = ""
        self.export_sharepoint_01_path: str = ""
        self.export_sharepoint_02_path: str = ""
        self.tech_password: str = "230167"
        self.ops_password: str = "111111"
        self.is_stack_light_enabled: bool = False

        #Create table structures
        self.logger.info('Setting up tables...')
        self.connection = sqlite3.connect('/home/tech/pi-networked-counter/database.db',detect_types=sqlite3.PARSE_DECLTYPES | sqlite3.PARSE_COLNAMES, check_same_thread=False)
        self.sqlcursor: sqlite3.Cursor = self.connection.cursor()
        self.sqlcursor.execute('PRAGMA foreign_keys = ON')
        self.sqlcursor.execute('CREATE TABLE IF NOT EXISTS settings(setting_id TEXT PRIMARY KEY UNIQUE, title TEXT, value TEXT);')
        self.sqlcursor.execute('CREATE TABLE IF NOT EXISTS products(product_id INTEGER PRIMARY KEY UNIQUE, title TEXT, target_count INTEGER, target_pace INTEGER, product_weight REAL);')
        self.sqlcursor.execute('CREATE TABLE IF NOT EXISTS counts(count_id INTEGER PRIMARY KEY, countdatetime INTEGER UNIQUE NOT NULL, machine TEXT NOT NULL, reject INTEGER NOT NULL, product_id INTEGER NOT NULL, FOREIGN KEY(product_id) REFERENCES products (product_id) ON DELETE CASCADE);')
        result = self.sqlcursor.execute('SELECT EXISTS (SELECT 1 FROM settings);').fetchone()
        if not result[0]:
            self.logger.info('Settings not found, creating defaults')
            self.sqlcursor.execute('INSERT INTO settings VALUES (?,?,?);', ('operation_mode', 'Operation Mode', "0"))
            self.sqlcursor.execute('INSERT INTO settings VALUES (?,?,?);', ('bounce_time', 'Bounce Time (s)', "0.1"))
            self.sqlcursor.execute('INSERT INTO settings VALUES (?,?,?);', ('infeed_pin', 'Infeed Pin', "17"))
            self.sqlcursor.execute('INSERT INTO settings VALUES (?,?,?);', ('outfeed_pin', 'Outfeed Pin', "23"))
            self.sqlcursor.execute('INSERT INTO settings VALUES (?,?,?);', ('stack_pin_green', 'Stack Green', "27"))
            self.sqlcursor.execute('INSERT INTO settings VALUES (?,?,?);', ('stack_pin_yellow', 'Stack Yellow', "22"))
            self.sqlcursor.execute('INSERT INTO settings VALUES (?,?,?);', ('stack_pin_red', 'Stack Red', "24"))
            self.sqlcursor.execute('INSERT INTO settings VALUES (?,?,?);', ('machine_name', 'Machine Name', "sample_machine"))
            self.sqlcursor.execute('INSERT INTO settings VALUES (?,?,?);', ('export_backend', 'Export Backend', "0"))
            self.sqlcursor.execute('INSERT INTO settings VALUES (?,?,?);', ('is_export_folder_01_enabled', 'Export Folder 01 Enabled', "False"))
            self.sqlcursor.execute('INSERT INTO settings VALUES (?,?,?);', ('is_export_folder_02_enabled', 'Export Folder 02 Enabled', "False"))
            self.sqlcursor.execute('INSERT INTO settings VALUES (?,?,?);', ('is_export_single_file_enabled', 'Export Single File Enabled', "False"))
            self.sqlcursor.execute('INSERT INTO settings VALUES (?,?,?);', ('export_folder_01_path', 'Export Folder 01 Path', ""))
            self.sqlcursor.execute('INSERT INTO settings VALUES (?,?,?);', ('export_folder_02_path', 'Export Folder 02 Path', ""))
            self.sqlcursor.execute('INSERT INTO settings VALUES (?,?,?);', ('export_folder_01_frequency', 'Export Folder 01 Frequency', "1"))
            self.sqlcursor.execute('INSERT INTO settings VALUES (?,?,?);', ('export_folder_02_frequency', 'Export Folder 02 Frequency', "1"))
            self.sqlcursor.execute('INSERT INTO settings VALUES (?,?,?);', ('export_folder_01_period', 'Export Folder 01 Period', "1"))
            self.sqlcursor.execute('INSERT INTO settings VALUES (?,?,?);', ('export_folder_02_period', 'Export Folder 02 Period', "1"))
            self.sqlcursor.execute('INSERT INTO settings VALUES (?,?,?);', ('is_export_sharepoint_01_enabled', 'Export Sharepoint 01 Enabled', "False"))
            self.sqlcursor.execute('INSERT INTO settings VALUES (?,?,?);', ('is_export_sharepoint_02_enabled', 'Export Sharepoint 02 Enabled', "False"))
            self.sqlcursor.execute('INSERT INTO settings VALUES (?,?,?);', ('export_sharepoint_01_frequency', 'Export Sharepoint 01 Frequency', "1"))
            self.sqlcursor.execute('INSERT INTO settings VALUES (?,?,?);', ('export_sharepoint_02_frequency', 'Export Sharepoint 02 Frequency', "1"))
            self.sqlcursor.execute('INSERT INTO settings VALUES (?,?,?);', ('export_sharepoint_01_period', 'Export Sharepoint 01 Period', "1"))
            self.sqlcursor.execute('INSERT INTO settings VALUES (?,?,?);', ('export_sharepoint_02_period', 'Export Sharepoint 02 Period', "1"))
            self.sqlcursor.execute('INSERT INTO settings VALUES (?,?,?);', ('export_sharepoint_01_site_id', 'Export Sharepoint 01 Site ID', ""))
            self.sqlcursor.execute('INSERT INTO settings VALUES (?,?,?);', ('export_sharepoint_02_site_id', 'Export Sharepoint 02 Site ID', ""))
            self.sqlcursor.execute('INSERT INTO settings VALUES (?,?,?);', ('export_sharepoint_01_list_id', 'Export Sharepoint 01 List ID', ""))
            self.sqlcursor.execute('INSERT INTO settings VALUES (?,?,?);', ('export_sharepoint_02_list_id', 'Export Sharepoint 02 List ID', ""))
            self.sqlcursor.execute('INSERT INTO settings VALUES (?,?,?);', ('export_sharepoint_01_path', 'Export Sharepoint 01 Path', ""))
            self.sqlcursor.execute('INSERT INTO settings VALUES (?,?,?);', ('export_sharepoint_02_path', 'Export Sharepoint 02 Path', ""))
            self.sqlcursor.execute('INSERT INTO settings VALUES (?,?,?);', ('tech_password', 'Tech Password', "230167"))
            self.sqlcursor.execute('INSERT INTO settings VALUES (?,?,?);', ('ops_password', 'Ops Password', "111111"))
            self.sqlcursor.execute('INSERT INTO settings VALUES (?,?,?);', ('is_stack_light_enabled', 'Stack Light Enabled', "False"))
            self.connection.commit()

        result: list[Any] = self.sqlcursor.execute('SELECT * FROM settings').fetchall()
        if result:
            for setting in result:
                match setting[0]:
                    case 'operation_mode':
                        self.operation_mode = int(setting[2])
                    case 'bounce_time':
                        self.bounce_time = float(setting[2])
                    case 'infeed_pin':
                        self.infeed_pin = int(setting[2])
                    case 'outfeed_pin':
                        self.outfeed_pin = int(setting[2])
                    case 'stack_pin_green':
                        self.stack_pin_green = int(setting[2])
                    case 'stack_pin_yellow':
                        self.stack_pin_yellow = int(setting[2])
                    case 'stack_pin_red':
                        self.stack_pin_red = int(setting[2])
                    case 'machine_name':
                        self.machine_name = str(setting[2])
                    case 'export_backend':
                        self.export_backend = int(setting[2])
                    case 'is_export_folder_01_enabled':
                        self.is_export_folder_01_enabled = setting[2] == 'True'
                    case 'is_export_folder_02_enabled':
                        self.is_export_folder_02_enabled = setting[2] == 'True'
                    case 'is_export_single_file_enabled':
                        self.is_export_single_file_enabled = setting[2] == 'True'
                    case 'export_folder_01_path':
                        self.export_folder_01_path = str(setting[2])
                    case 'export_folder_02_path':
                        self.export_folder_02_path = str(setting[2])
                    case 'export_folder_01_frequency':
                        self.export_folder_01_frequency = int(setting[2])
                    case 'export_folder_02_frequency':
                        self.export_folder_02_frequency = int(setting[2])
                    case 'export_folder_01_period':
                        self.export_folder_01_period = int(setting[2])
                    case 'export_folder_02_period':
                        self.export_folder_02_period = int(setting[2])
                    case 'is_export_sharepoint_01_enabled':
                        self.is_export_sharepoint_01_enabled = setting[2] == 'True'
                    case 'is_export_sharepoint_02_enabled':
                        self.is_export_sharepoint_02_enabled = setting[2] == 'True'
                    case 'export_sharepoint_01_path':
                        self.export_sharepoint_01_path = str(setting[2])
                    case 'export_sharepoint_02_path':
                        self.export_sharepoint_02_path = str(setting[2])
                    case 'export_sharepoint_01_frequency':
                        self.export_sharepoint_01_frequency = int(setting[2])
                    case 'export_sharepoint_02_frequency':
                        self.export_sharepoint_02_frequency = int(setting[2])
                    case 'export_sharepoint_01_period':
                        self.export_sharepoint_01_period = int(setting[2])
                    case 'export_sharepoint_02_period':
                        self.export_sharepoint_02_period = int(setting[2])
                    case 'export_sharepoint_01_site_id':
                        self.export_sharepoint_01_site_id = str(setting[2])
                    case 'export_sharepoint_02_site_id':
                        self.export_sharepoint_02_site_id = str(setting[2])
                    case 'export_sharepoint_01_list_id':
                        self.export_sharepoint_01_list_id = str(setting[2])
                    case 'export_sharepoint_02_list_id':
                        self.export_sharepoint_02_list_id = str(setting[2])
                    case 'tech_password':
                        self.tech_password = str(setting[2])
                    case 'ops_password':
                        self.ops_password = str(setting[2])
                    case 'is_stack_light_enabled':
                        self.is_stack_light_enabled = setting[2] == 'True'
                    case _:
                        pass

        self.setup_sensors()
        self.set_ui()
        self.get_all_products()

    def check_internet_availability(self):
        try:
            socket.create_connection(('8.8.8.8', 53), timeout=5)
            return True
        except OSError:
            return False

    def setup_sensors(self):
        self.logger.info('Setting up sensors...')
        self.infeed_sensor: DigitalInputDevice = DigitalInputDevice(pin=self.infeed_pin, pull_up=True, bounce_time=self.bounce_time)
        self.outfeed_sensor: DigitalInputDevice = DigitalInputDevice(pin=self.outfeed_pin, pull_up=True, bounce_time=self.bounce_time)
        self.infeed_sensor.when_activated = self.sensor_activated
        self.outfeed_sensor.when_activated = self.sensor_activated
        self.infeed_sensor.when_deactivated = self.sensor_deactivated
        self.outfeed_sensor.when_deactivated = self.sensor_deactivated
        self.stack_output_green = LED(pin=self.stack_pin_green, initial_value=False)
        self.stack_output_yellow = LED(pin=self.stack_pin_yellow, initial_value=False)
        self.stack_output_red = LED(pin=self.stack_pin_red, initial_value=False)

    def setup_export(self):
        self.logger.info('Setting up exports...')
        self.is_export_setup = False
        if self.export_backend == ExportBackend.NONE.value:
            return
        elif self.export_backend == ExportBackend.FOLDER.value:
            if not self.is_export_folder_01_enabled and not self.is_export_folder_02_enabled:
                self.logger.error('Folder export selected but neither exports are enabled')
                return
            if self.is_export_folder_01_enabled and self.export_folder_01_path == "":
                self.logger.error('Folder export 1 selected but no path given')
                return
            if self.is_export_folder_02_enabled and self.export_folder_02_path == "":
                self.logger.error('Folder export 2 selected but no path given')
                return
            self.is_export_setup = True
        elif self.export_backend == ExportBackend.SHAREPOINT.value:
            if not self.is_export_sharepoint_01_enabled and not self.is_export_sharepoint_02_enabled:
                self.logger.error('Sharepoint export selected but neither exports are enabled')
                return
            if self.is_export_sharepoint_01_enabled and self.export_sharepoint_01_path == "":
                self.logger.error('Sharepoint export 1 selected but no path given')
                return
            if self.is_export_sharepoint_02_enabled and self.export_sharepoint_02_path == "":
                self.logger.error('Sharepoint export 2 selected but no path given')
                return
            if self.is_export_sharepoint_01_enabled and self.export_sharepoint_01_site_id == "":
                self.logger.error('Sharepoint export 1 selected but no site id given')
                return
            if self.is_export_sharepoint_02_enabled and self.export_sharepoint_02_site_id == "":
                self.logger.error('Sharepoint export 2 selected but no site id given')
                return
            if self.is_export_sharepoint_01_enabled and self.export_sharepoint_01_list_id == "":
                self.logger.error('Sharepoint export 1 selected but no list id given')
                return
            if self.is_export_sharepoint_02_enabled and self.export_sharepoint_02_list_id == "":
                self.logger.error('Sharepoint export 2 selected but no list id given')
                return

            self.sharepoint_export = SharepointExport()
            self.is_export_setup = True
        
    def set_ui(self):
        self.logger.info('Setting up ui...')
        self.setWindowFlags(Qt.WindowType.FramelessWindowHint)
        self.showFullScreen()
        self.buttonExit.clicked.connect(self.quit_app)
        self.productList.itemSelectionChanged.connect(self.product_list_selection_changed)
        self.buttonLoadProduct.clicked.connect(self.load_product)
        self.buttonResetCount.clicked.connect(self.reset_counts)
        self.buttonSaveProduct.clicked.connect(self.update_product)
        self.buttonSaveNewProduct.clicked.connect(self.create_product)
        self.buttonDeleteProduct.clicked.connect(self.delete_product)
        self.spinBoxInfeedPin.valueChanged.connect(self.infeed_pin_changed)
        self.spinBoxOutfeedPin.valueChanged.connect(self.outfeed_pin_changed)
        self.doubleSpinBoxBounceTime.valueChanged.connect(self.bounce_time_changed)
        self.pushButtonTriggerGoodCount.clicked.connect(self.testing_trigger_good_count)
        self.pushButtonTriggerRejectCount.clicked.connect(self.testing_trigger_reject_count)
        #Stacklight
        self.checkBoxEnableStackLight.stateChanged.connect(self.enable_stack_light_changed)
        self.spinBoxStackLightGreenOutput.valueChanged.connect(self.stack_light_pin_green_changed)
        self.spinBoxStackLightYellowOutput.valueChanged.connect(self.stack_light_pin_yellow_changed)
        self.spinBoxStackLightRedOutput.valueChanged.connect(self.stack_light_pin_red_changed)
        self.comboBoxOperationMode.currentIndexChanged.connect(self.operation_mode_changed)
        self.lineEditMachineName.textChanged.connect(self.machine_name_changed)
        self.lineEditLogin.returnPressed.connect(self.login_attempt)
        self.buttonLogin.released.connect(self.login_attempt)
        self.buttonToggleFullscreen.released.connect(self.toggle_fullscreen)
        #Exports
        self.comboBoxExportBackend.currentIndexChanged.connect(self.export_backend_changed)
        self.checkBoxFolderExport01.stateChanged.connect(self.folder_export_01_changed)
        self.checkBoxFolderExport02.stateChanged.connect(self.folder_export_02_changed)
        self.checkBoxSingleFileMode.stateChanged.connect(self.single_file_mode_changed)
        self.checkBoxSharepointExport01.stateChanged.connect(self.sharepoint_export_01_changed)
        self.checkBoxSharepointExport02.stateChanged.connect(self.sharepoint_export_02_changed)
        self.spinBoxFolderExport01Frequency.valueChanged.connect(self.folder_frequency_01_changed)
        self.spinBoxFolderExport02Frequency.valueChanged.connect(self.folder_frequency_02_changed)
        self.spinBoxSharepointExport01Frequency.valueChanged.connect(self.sharepoint_frequency_01_changed)
        self.spinBoxSharepointExport02Frequency.valueChanged.connect(self.sharepoint_frequency_02_changed)
        self.spinBoxFolderExport01Period.valueChanged.connect(self.folder_period_01_changed)
        self.spinBoxFolderExport02Period.valueChanged.connect(self.folder_period_02_changed)
        self.spinBoxSharepointExport01Period.valueChanged.connect(self.sharepoint_period_01_changed)
        self.spinBoxSharepointExport02Period.valueChanged.connect(self.sharepoint_period_02_changed)
        self.lineEditFolderExport01Path.textChanged.connect(self.folder_path_01_changed)
        self.lineEditFolderExport02Path.textChanged.connect(self.folder_path_02_changed)
        self.lineEditSharepointExport01Path.textChanged.connect(self.sharepoint_path_01_changed)
        self.lineEditSharepointExport02Path.textChanged.connect(self.sharepoint_path_02_changed)
        self.lineEditSharepointExport01SiteID.textChanged.connect(self.sharepoint_site_id_01_changed)
        self.lineEditSharepointExport02SiteID.textChanged.connect(self.sharepoint_site_id_02_changed)
        self.lineEditSharepointExport01ListID.textChanged.connect(self.sharepoint_list_id_01_changed)
        self.lineEditSharepointExport02ListID.textChanged.connect(self.sharepoint_list_id_02_changed)
        self.export_01_timer.timeout.connect(self.export_data_01)
        self.export_02_timer.timeout.connect(self.export_data_02)
        self.pushButtonClearCounDatabase.released.connect(self.clear_count_database)
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

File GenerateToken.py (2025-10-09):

#! /usr/bin/env python3

import json
import sys
import logging
import tomllib
from typing import Dict, Any, List
from pathlib import Path
from datetime import datetime
from msal import PublicClientApplication # pyright: ignore[reportUnknownVariableType, reportAttributeAccessIssue]
from msal_extensions import PersistedTokenCache, build_encrypted_persistence, FilePersistence # pyright: ignore[reportUnknownVariableType, reportAttributeAccessIssue]

class Colors:
    OKCYAN = '\033[96m'
    OKGREEN = '\033[92m'
    WARNING = '\033[93m'
    FAIL = '\033[91m'
    ENDC = '\033[0m'

class Token(object):
    def __init__(self, location:str=".cache", plaintext:bool=False, setting_file: str = '.setup.toml'):
        self.logger = logging.getLogger(__name__)
        Path('./logs/').mkdir(parents=True, exist_ok=True)
        logging.basicConfig(filename='./logs/.token_generator_debug_' + datetime.now().strftime('%Y-%m-%d_%H-%M') + '.log', level=logging.DEBUG)
        self.settings: Dict[str, Any] = {}
        self.client_id: str = ''
        self.auth: str = ''
        self.endpoint: str = ''
        self.scopes: List[str] = []
        self.LoadSettings(setting_file)
        self.persistance: FilePersistence = self.build_persistence(location=location, plaintext=plaintext) # pyright: ignore[reportUnknownMemberType]
        self.cache: PersistedTokenCache = PersistedTokenCache(persistence=self.persistance) # pyright: ignore[reportUnknownMemberType]
        self.app: PublicClientApplication = PublicClientApplication(
            client_id = self.client_id,
            authority = self.auth,
            token_cache = self.cache, # pyright: ignore[reportUnknownMemberType]
            )

    def LoadSettings(self, setting_file: str) -> None:
        with open(setting_file, 'rb') as file:
            self.settings: Dict[str, Any] = tomllib.load(file)
            if 'sharepoint' in self.settings: 
                if 'authority' in self.settings['sharepoint']:
                    self.auth = self.settings['sharepoint']['authority']
                if 'client' in self.settings['sharepoint']:
                    self.client_id = self.settings['sharepoint']['client']
                if 'scopes' in self.settings['sharepoint']:
                    self.scopes = self.settings['sharepoint']['scopes'].split()
                if 'endpoint' in self.settings['sharepoint']:
                    self.endpoint = self.settings['sharepoint']['endpoint']
            else:
                self.logger.warning('Unable to load sharepoint settings')

    def build_persistence(self,location: str, plaintext: bool) -> FilePersistence: # pyright: ignore[reportUnknownParameterType]
        """
           Build a suitable persistence instance based your current OS. 
           Aquire persistance using encryption or plain text as fallback if enabled.
           Note: This sample stores both encrypted persistence and plaintext persistence into same location,
           therefore their data would likely override with each other.
        """
        if plaintext:
            self.logger.info('Attempting plaintext persistance...')
            try:
                return FilePersistence(location) # pyright: ignore[reportUnknownVariableType]
            except:
                self.logger.error('Failed to create plaintext persistance.')
                raise ValueError('Failed to create plaintext persistance.')
        else:
            self.logger.info('Attempting encrypted persistance...')
            try:
                return build_encrypted_persistence(location) # pyright: ignore[reportUnknownVariableType]
            except:
                self.logger.error('Failed to create encrypted persistance.')
                raise ValueError('Failed to create encrypted persistance.')

    def build_persistence_new(self,location: str, plaintext_fallback: bool = True) -> FilePersistence: # pyright: ignore[reportUnknownParameterType]
        """
           Build a suitable persistence instance based your current OS. 
           Aquire persistance using encryption or plain text as fallback if enabled.
           Note: This sample stores both encrypted persistence and plaintext persistence into same location,
           therefore their data would likely override with each other.
        """
        try:
            self.logger.info('Attempting encrypted persistance...')
            return build_encrypted_persistence(location) # pyright: ignore[reportUnknownVariableType]
        except:
            """
                On Linux, encryption exception will be raised during initialization.
                On Windows and macOS, they won't be detected here,
                but will be raised during their load() or save().
            """
            if not plaintext_fallback:
                self.logger.warning('Plaintext fallback disabled and unable to aquire encrypted persistance.')
                raise ValueError('Plaintext fallback disabled and unable to aquire encrypted persistance.')
            self.logger.warning('Encryption not available, using plaintext...')
            return FilePersistence(location) # pyright: ignore[reportUnknownVariableType]
    
    def aquire_token(self) -> Dict[str, str]:
        """
        Get existing token or create a new token
        :return: dict with token information or empty dict
        """
        new_token: None | Dict[str, str] = None
        accounts: List[Dict[str, str]] = self.app.get_accounts() # pyright: ignore[reportUnknownVariableType, reportUnknownMemberType]

        if accounts:
            self.logger.info('Checking cache for accounts and tokens...')
            new_token = self.app.acquire_token_silent(scopes=self.scopes, account=accounts[0]) # pyright: ignore[reportUnknownMemberType, reportUnknownVariableType]

        if not new_token:
            self.logger.info('Creating new token..')
            flow: Dict[str, Any] = self.app.initiate_device_flow(scopes=self.scopes) # pyright: ignore[reportUnknownMemberType, reportUnknownVariableType]
            if not "user_code" in flow:
                self.logger.error('Failed to create flow: %s'  % json.dumps(flow, indent=4))
                raise ValueError("Failed to create flow: %s" % json.dumps(flow, indent=4))
            if 'message' in flow:
                print(flow["message"]) # pyright: ignore[reportUnknownArgumentType]
                self.logger.info(flow["message"]) # pyright: ignore[reportUnknownArgumentType]
            sys.stdout.flush()
            new_token = self.app.acquire_token_by_device_flow(flow) # pyright: ignore[reportUnknownMemberType, reportUnknownVariableType]
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

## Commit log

2024-07-27 Initial commit
    Initial setup scripts and gitignore
    IO test for pi distance sensors
    Initial qt display with sqlite backend
2024-07-29 Setup debug page
    - Change setting page to debug page
    - Add monitors for raw sensor data
    - Add toggles for various settings
2024-07-29 Setup distance sensors
    - Move sensor variables into class
    - Setup base setting options
    - Setup threads and timer for sensor checks
2024-07-30 Add images and models
    - Add models for case
    - Add iamges for readme
    [NetworkCounter_Case_Back.3mf, NetworkCounter_Case_Back.FCStd, NetworkCounter_Case_Bracket_Long.3mf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]
2024-09-13 update models
    - update main assembly
    - add sensor case models
    - update readme
    update form
    - clean up ui
    - add section for target count
    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
    [Generic_Rod_Bracket.FCStd, Generic_Rod_Bracket_9mm.FCStd, NetworkCounter_Case_Back.3mf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]
2024-12-20 Add clear database button, prevent oversized ui
    [main.py]
2025-04-04 Model updates
    [Generic_Rod_Bracket.FCStd, Generic_Rod_Bracket_9mm.FCStd, NetworkCounter_Adapter_13mmHorizontal_9mmVertical.3mf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]
2025-04-04 Sharepoint export error logging
    [GenerateToken.py, SharepointExport.py]
2026-03-07 Update setup and diagrams
    [Assembly.kicad_pcb, Assembly.kicad_sch, CM5IO.kicad_pcb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]

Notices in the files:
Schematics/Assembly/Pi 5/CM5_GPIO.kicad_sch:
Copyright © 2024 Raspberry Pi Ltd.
